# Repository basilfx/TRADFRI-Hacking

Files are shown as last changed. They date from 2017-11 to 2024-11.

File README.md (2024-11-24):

# Hacking IKEA TRÅDFRI

  * [Introduction](#introduction)
  * [TRÅDFRI modules](#trådfri-modules)
  * [Product teardowns](#product-teardowns)
  * [Firmware hacking](#firmware-hacking)
  * [Other hacks](#other-hacks)
    * [EZSP Zigbee coordinator](#ezsp-zigbee-coordinator)
    * [Zigbee router](#zigbee-router)
    * [FLOALT brightness hack](#floalt-brightness-hack)
    * [Shortcut button "no double press" hack](#shortcut-button-no-double-press-hack)
    * [DOOM](#doom)
  * [Sources](#sources)
  * [License](#license)
  * [Safety](#safety)
  * [Disclaimer](#disclaimer)

## Introduction
The [IKEA TRÅDFRI](http://www.ikea.com/us/en/catalog/categories/departments/lighting/36812/)
family of products provide you with several home automation solutions that
interconnect using [Zigbee Light Link](http://www.zigbee.org/zigbee-for-developers/applicationstandards/zigbee-light-link/).
While the line-up initially only included lighting products, it includes power
switches and wireless window blinds as well.

Many of the TRÅDFRI are quite simple. For instance, if we take a simple light
bulb, it contains:

* Power supply
* LED driver
* IKEA TRÅDFRI module

The IKEA TRÅDFRI module is used in many of their products, and is actually
a small piece of circuit board with a few GPIO pins exposed. These pins are
then used to control the LED driver.

The goal of this project is to provide information about the IKEA TRÅDFRI
modules and products, so you can start hacking them. For example:

* Take apart a light bulb, and use the module board, to control your own
  lighting solutions.
* Create custom boards for wall-mounted switches based on their dimmer buttons.
* Patch the firmware to dimming capabilies.
* Repurposing the modules by writing your own firmware.

To find relevant products, I have compiled a list of IKEA TRÅDFRI products in
[PRODUCTS.md](PRODUCTS.md). A teardown of has also been provided for some
products.

## TRÅDFRI modules
So far, a few variations of the TRÅDFRI modules have been identified. They are
all using microcontrollers manufactured by Silicon Labs. The modules that have
been identified are:

* ICC-1
* ICC-A-1
* MGM210L

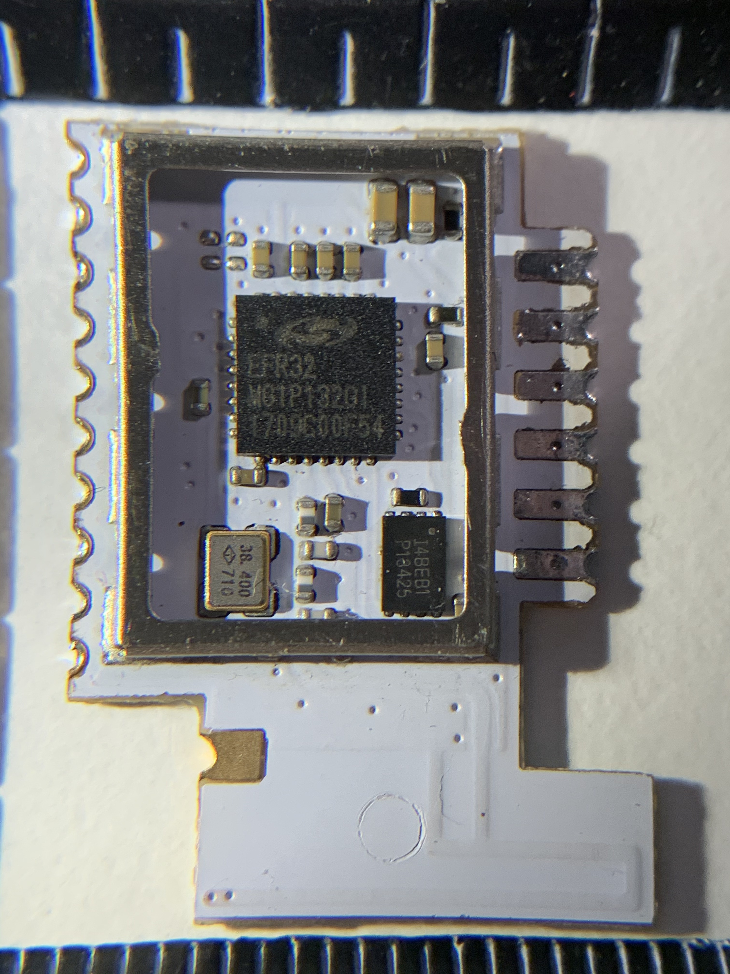
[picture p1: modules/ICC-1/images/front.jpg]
Front of IKEA TRÅDFRI module (ICC-1)
[](modules/ICC-1/images/front.jpg)
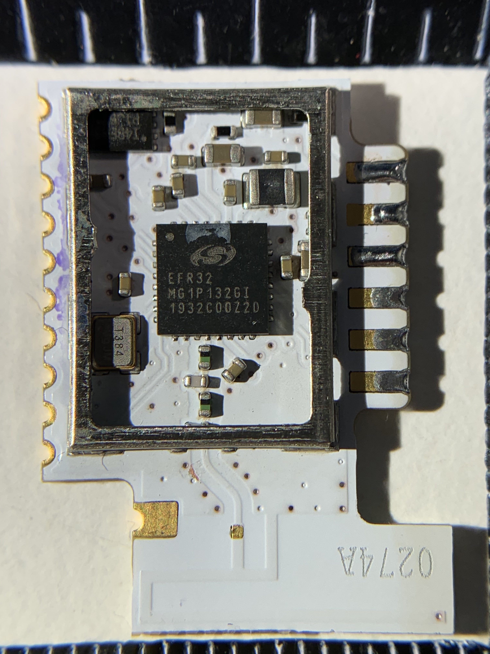
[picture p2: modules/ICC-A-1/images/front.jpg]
Front of IKEA TRÅDFRI module (ICC-A-1)
[](modules/ICC-A-1/images/front.jpg)
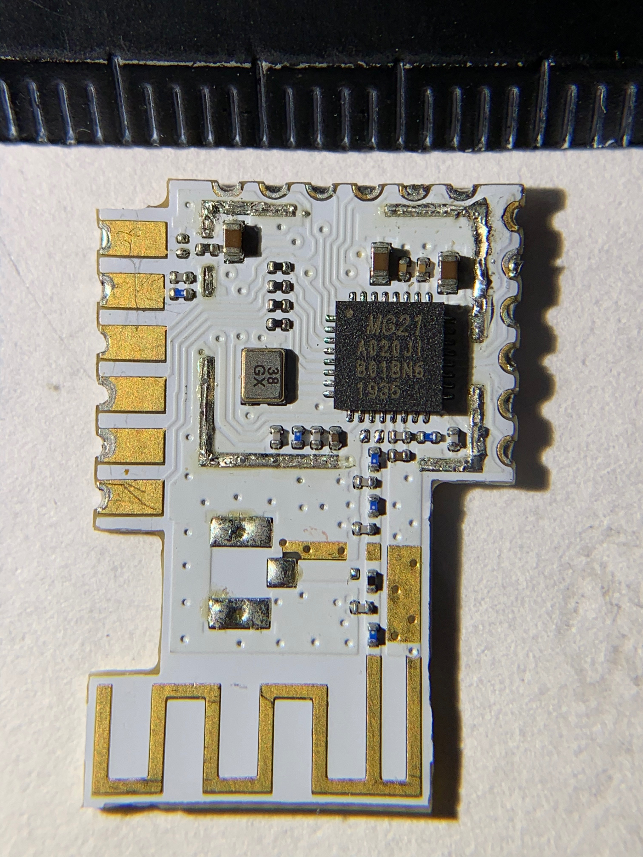
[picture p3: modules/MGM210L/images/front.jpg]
Front of IKEA TRÅDFRI module (MGM210L)
[](modules/MGM210L/images/front.jpg)

Some other products, such as the line-up of remote controls, have a dedicated
circuit board that integrate a microcontroller directly (i.e. no separate
module board).

More details and pictures on these modules can be found in
[MODULES.md](MODULES.md).

## Product teardowns
Be sure to check out the [PRODUCTS.md](PRODUCTS.md) on more details on products
that have been reversed-engineered. There are product teardown photos,
schematics, firmware dumps, firmware analysis and more.

If you have any products not in the list, please contribute! If you have any
teardown photos, firmware files or other information, I'd like to add it to the
list.

## Firmware hacking
The TRÅDFRI products use an ARM Cortex M-series microcontroller. There are
plenty of tools for these types of microcontrollers to get started on reversing
firmware files and write your own firmwares.

* Find dumps of firmware files in the OTA [folder](contrib/firmwares/ikea-ota).
* Checkout the [RIOT-OS](contrib/firmwares/riot-os) folder for more information
  on custom firmware development. You can use this as a starting point.
* Reference information on dumping firmware images [here](docs/firmware_dumping/README.md).
* Learn how to inspect the firmware for reverse-enginering in [this](docs/firmware_reversing)
  folder.
* Build a [development board](contrib/pcbs/devboard) for easy access to a
  TRÅDFRI module's pins.

## Other hacks
Some people have came up with alternative uses for the TRÅDFRI modules. Here
are a few:

### EZSP Zigbee coordinator
It is possible to load the Silicon Labs EmberZNet Zigbee coordinator firmware
on an ICC-1 or ICC-A-1. This allows you to use the module to set-up your own
Zigbee network.

MattWestb has provided a guide and firmware [here](https://github.com/MattWestb/IKEA-TRADFRI-ICC-A-1-Module).

### Zigbee router
Several users have [modified](https://community.home-assistant.io/t/sonoff-zbbridge-sonoff-zigbee-bridge-from-itead/187346/88)
the TRÅDFRI routers to improve the performance, by adding an external antenna.

This applies to the ICC-A-1 modules only, but it should be very interesting
if a the TRÅDFRI routers will use the newer MGM210L modules, because they offer
a solder pad for an external antenna.

### FLOALT brightness hack
[zw](https://github.com/zw) has patched the firmware of his FLOALT LED panel to
have an improved range of brightness levels. A guide to perform the firmware
patch has been contributed [here](https://github.com/zw/TRADFRI-Hacking/tree/master/hacks/L1527).

### Shortcut button "no double press" hack
Simon has [patched](https://github.com/nomis/ikea-tradfri-e1812) the firmware
of the E1812 shortcut button to disable the double press feature, getting rid
of the 400ms delay on single presses.

### DOOM
A version of DOOM was port to the IKEA TRÅDFRI MGM210L modules, including a
custom contrller. The project is documented [here](https://next-hack.com/index.php/2021/06/12/lets-port-doom-to-an-ikea-tradfri-lamp/)
and the source code can be found [here](https://github.com/next-hack/MG21DOOM).

## Sources
I have gathered some information from the following sources:

* [IKEA TRÅDFRI hacking](https://tradfri.blogspot.nl)
* [TRÅDFRI: ESP8266-Lampen-Gateway](https://www.heise.de/make/artikel/Ikea-Tradfri-Anleitung-fuer-ein-ESP8266-Lampen-Gateway-3598411.html)
* [TRÅDFRI Zigbee Light Link module](https://diystuff.nl/tradfri/tradfri-zigbee-light-link-module)
* [TRÅDFRI Wall switch](https://wiki.permejdal.dk/TR%C3%85DFRI_wall_switch)

## License
See the [LICENSE.md](LICENSE.md) file (CC-BY-4.0).

## Safety
Some TRÅDFRI products are mains powered. If you don't know what that means, then
stop right now. Please read [this](docs/working_safely) for more information on
working safely on mains-connected devices.

## Disclaimer
This page and its content is not affiliated with IKEA of Sweden AB.

The purpose of this project is to learn and improve using reverse engineering
techniques. Use this information on your own risk. You will void your warranty.

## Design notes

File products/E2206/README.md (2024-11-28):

# E2206
INSPELNING smart switch with energy monitoring.

This is very similar to the [E2204](../E2204), but has a few additional parts
populated for energy monitoring.

## Details

* Potted: tiny bit
* Module: unidentified

## Teardown
Remove the screw in the middle (security screw). Then use a pry tool to remove
the front casing, paying attention to the raised border and the tabs on all
four sides

Once inside, remove the two small screw from the main board. One corner is
slightly potted, but it is quite brittle and does not really adhere to the
casing. You can heat up the corner using a heat gun to make it softer.

Then firmly push on the contact pins to remove the board from its housing.
Place the pins on a hard surface, then push the case down. Be aware that the
switch domes must be bent inwards, otherwise they will be damaged.

* [Images](images)

## Parts

* U3: [Hiliwei Tech HLW8110](https://redmine.laas.fr/attachments/download/3444/DS_HLW8110_HLW8112_EN_Rev1.01%20.pdf)

## Sources

* https://www.ikea.com/us/en/manuals/tretakt-plug-smart__AA-2396101-2-100.pdf

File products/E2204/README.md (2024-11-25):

# E2204
TRETAKT smart switch

## Details

* Potted: no
* Module: unidentified

## Teardown
Remove the screw in the middle (security screw). Then use a pry tool to remove
the front casing, paying attention to the tabs on all four sides.

Once inside, remove the two small screw from the main board. Then gently push
on the contact pins to remove the board from its housing. Be careful, because
you can easily damage the switches.

* [Images](images)

## Sources
* https://www.ikea.com/us/en/manuals/tretakt-plug-smart__AA-2396101-2-100.pdf

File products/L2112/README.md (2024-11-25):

# L2112
ORMANÄS LED strip, color/white spectrum, 4 m.

## Details

* Potted: no
* Module: MGM210L

## Teardown
The device can be easily opened. There are six tabs that keep the lid in place
(see pictures). Using a plastic pry tool, you should be able to open the device
without any damage.

* [Images](images)

## Sources

* https://www.ikea.com/us/en/assembly_instructions/ormanas-led-strip-smart-draadloos-dimbaar-gekleurd-en-wit-spectrum__AA-2364567-3-2.pdf

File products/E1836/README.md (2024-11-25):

# E1836
ÅSKVÄDER on/off button.

## Details

* Potted: no
* Module: MGM210L

## Teardown
This product is securely enclosed, and can only be opened destructively. I
found it the easiest to use a hacksaw (or a Dremel) to cut the sides, so it can
be opened up.

* [Images](images)

## Sources
* https://www.ikea.com/us/en/assembly_instructions/askvader-aan-uitknop__AA-2248628-2-2.pdf

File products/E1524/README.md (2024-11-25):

# E1524
TRÅDFRI remote controller.

## Pinout

### Module

* PB15 -> Color temperature
* PB14 -> Dim -
* PC10 -> On/Off
* PB13 -> TX
* PA1 -> Dim +
* PA0 -> TouchLink button

## Sources

* https://www.ikea.com/us/en/manuals/tradfri-remote-control__AA-2144721-1_pub.pdf
* https://www.heise.de/make/artikel/Ikea-Tradfri-Anleitung-fuer-ein-ESP8266-Lampen-Gateway-3598411.html

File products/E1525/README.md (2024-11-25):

# E1525
TRÅDFRI motion sensor.

## Details:

* Battery: 2x CR2032

## Teardown
The module is easy to take apart, and debug wires can be soldered on without
separating the radio / MCU PCB from the carrier PCB. The carrier board is
labelled "D-Sensor-A1-01-A-V2.0".

* [Images](images)
* [Schematics](schematics)

## Pinout

### Module

| Module Pin | Signal |
|---|---|
| PA0 | Switch Input |
| PA1 | Timer Input (Voltage Divider) |
| PB12 | Nothing? Has a capacitor position |
| PB13 | Photoresistor Analog |
| PB14 | PIR Interrupt |
| PB15 | Day/Night Analog |
| PC10 | PIR Serial Connection |

### PCB

| Test Point | Signal |
|---|---|
| TP1_X | Day/Night Potentiometer Analog |
| TP2_X | Photoresistor Analog Output |
| TP3_X | Ground |
| TP4_X | Switch Output |
| TP5_X | Timer Potentiometer Analog |
| TP7_X | LED |
| TP8_X | Power Supply |

* Time selection dial (R13): PA1 (Looks like a potentiometer between R12 high
  side and a FET to GND enabled directly by PB14.)
* Day/night selection dial (R15): PB15 (Dito, with resistor R14 and same
  transistor.)
* Pairing button (S1): Silicone rubber button puling PA0 directly to GND

The motion detection dome is connected (one pin directly, one indirectly) to
an "E93196C 5090C 9A" labelled 8-pin chip to which also PC10 and PB14 are
connected (needs further investigation).

## Sources

* https://www.ikea.com/us/en/manuals/tradfri-wireless-motion-sensor-white__AA-2145281-3.pdf

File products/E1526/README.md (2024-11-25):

# E1526
TRÅDFRI hub.

## Details

* Power supply: USB 5V 1A

## Protocol
An overview of the COAP protocol used by the gateway can be found
[here](https://github.com/glenndehaan/ikea-tradfri-coap-docs).

## Sources
* https://www.ikea.com/us/en/manuals/tradfri-poarta__AA-1954427-3_pub.pdf

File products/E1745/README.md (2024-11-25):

# E1745
TRÅDFRI motion sensor.

## Details

* Battery: 2x CR2032

## Teardown
Module is easy to take apart with the right tools, debug wires could be
soldered on without separating the radio from the carrier PCB. The carrier
board is labelled "D-SS-X2-01-A-V2.1" and the date printed is 2018-06-05.
Tradfri module markings visible are Draco1.0_105° and 0255C.

* [Images](images)

## Pinouts

### Module
TRÅDFRI Module (unverified):

* tK1 -> Day/Night selection button
* tK2 -> Pairing button
* tK3 -> Time selection button

The motion detection dome is connected (one pin directly, one indirectly) to
an "E93196B 0940A 60A" labelled 8-pin chip. This appears to be
[Elmos E931.96](https://www.elmos.com/english/products/sensor-ics/passive-infrared/pyroelectric-sensor-signal-processor-ssp/e93196.html).

### PCB
Various test points:

* VCC: `VDD`
* GND: `GND`
* Pairing BTN: `tK2`
* Day/Night BTN: `tK1`
* Time Select BTN: `tK3`
* ???: `AL`
* ???: `ENT`
* ???: `TX1`

## Sources
* https://www.ikea.com/us/en/manuals/tradfri-motion-sensor-kit__AA-1954408-1_pub.pdf

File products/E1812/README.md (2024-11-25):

# E1812
TRÅDFRI shortcut button.

## Teardown
* [Images](images)

## Sources
* https://www.ikea.com/us/en/manuals/tradfri-remote-control-white-smart__AA-2198134-5-100.pdf

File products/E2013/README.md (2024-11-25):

# E2013
PARASOLL door/window sensor.

## Details

### Battery
This sensor runs off a 1.2 or 1.5 AAA battery, which increases the size of the
sensor.

When connecting it to a 3V power supply, it does work. It might be possible
that the DC-DC converter can be omitted in this case. However, the hall-effect
sensor emits a higher voltage level that represents a closed state.

## Teardown
* [Images](images)

## Parts
* R1 - 1 M
* R2 - 1 M
* R3 - 100 k
* R7 - 200
* R12 - 0

* U1 - EFR32MG24B020F1536IM40 (microcontroller)
* U2 - ? (hall-effect sensor)
* U3 - OC6811 (DC-DC converter)

* Y1 - 39 Mhz

## Sources
* https://www.ikea.com/us/en/manuals/parasoll-sensor-puerta-ventana-inteligente-blanco__AA-2426062-2-2.pdf
* https://fcc.report/FCC-ID/FHO-E2013/

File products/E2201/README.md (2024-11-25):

# E2201
RODRET wireless dimmer.

## Teardown
* [Images](images)

## Sources
* https://www.ikea.com/us/en/manuals/rodret-wireless-dimmer-power-switch-smart-white__AA-2398767-2-100.pdf

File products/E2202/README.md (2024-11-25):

# E2202
BADRING water leakage sensor.

## Details
Powered by a single AAA cell, boosted to 3.0V by the onboard DC-DC converter.
The inner plastic retainer is held with plastic clips, which makes the device
very easy to disassemble.

Teardown images can be found with FCC ID FHO-E2202.

## Parts

- U1: EFR32MG21A010F1024IM32
- Q1: 2N3904
- Q2: 2N3904
- Q3: Si2301

## Pinout

- PA00 PIN2 (input, driven by Q2)
- PA01 CLK (test pad)
- PA02 TMS (test pad)
- PA03 S1 (button, with pull-up)
- PA05 LED+
- PA06 VBAT
- PB00 Buzzer (driven by Q1)
- PD01 TX (test pad)
- PD00 RX (test pad)
- PD04 PIN1 (output, driven by Q3)

## Notes

The device is sending out some pulses on PIN1 and listening for a signal on
PIN2. Frequency is unknown, voltage is the same as VCC (3.0V). The chip is
locked, mass erase is required to load your own code to it.

## Sources

* https://www.ikea.com/us/en/manuals/badring-sensor-foer-vattenlaeckage-smart__AA-2426054-2-2.pdf

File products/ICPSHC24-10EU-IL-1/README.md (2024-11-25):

# ICPSHC24-10EU-IL-1
Driver for wireless control, 10 W

## Teardown

* [Images](images)

## Sources

* https://www.ikea.com/us/en/assembly_instructions/tradfri-driver-for-wireless-control-smart-grey__AA-2056440-8-100.pdf

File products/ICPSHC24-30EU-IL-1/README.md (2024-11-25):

# ICPSHC24-30EU-IL-1
Driver for wireless control, 30 W

## Teardown

* [Images](images)

## Sources

* https://www.ikea.com/us/en/manuals/tradfri-driver-for-wireless-control-grey__AA-2344761-1-100.pdf

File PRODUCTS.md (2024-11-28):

# List of IKEA TRÅDFRI products

* [Introduction](#introduction)
* [Product overview](#product-overview)
* [Catalog](#catalog)
  * [Lighting](#lighting)
  * [Remotes](#remotes)
  * [Sensors](#sensors)
  * [Gateways](#gateways)
  * [Others](#others)

## Introduction
This list is a collection of the IKEA TRÅDFRI products, and their relevant
technical properties. Please help me to update this list.

## Product overview
IKEA has following products and product categories for the Smart Home series
(also called TRADFRI):

* Smart Home Gateway
* FLOALT (light panel)
* GUNNARP (ceiling/wall lamp)
* LEPTITER (spotlight)
* IRSTA  (worktop lighting)
* OMLOPP (spotlight)
* STRÖMLINJE (worktop lighting)
* SKYDRAG (worktop lighting)
* FYRTUR / KADRYL (window blinds)
* 5-button remote control (V1 and V2)
* 2-button dimmer/switch
* Wheel dimmer
* Shortcut button
* Motion detector (V1 and V2)
* Signal repeater + battery charger
* Switching outlet plug/mains
* LED driver 10 W with 3 connections
* LED Driver 30 W
* Bulb E27 1000 lm white/warmwhite
* Bulb E27 800 lm warmwhite
* Bulb E27 800 lm white/warmwhite transparent
* Bulb E27 600 lm color
* Bulb E14 600 lm color
* Bulb E14 600 lm white/warmwhite
* Bulb E27 250 lm filament gold
* Bulb GU10 400 lm warmwhite
* Bulb GU10 400 lm white/warmwhite
* Bulb GU10 350 lm color

## Catalog

### Lighting

* [L1529](products/L1529) - FLOALT LED light panel
* [L2112](products/L2112) - ORMANÄS LED strip, color/white spectrum, 4 m
* [LED1536G5](products/LED1536G5) - TRÅDFRI bulb E12/E14, white spectrum, globe, opal, 400 lm
* [LED1537R6](products/LED1537R6) - TRÅDFRI bulb GU10, white spectrum, 400 lm
* [LED1545G12](products/LED1545G12) - TRÅDFRI bulb E26/E27, white spectrum, globe, opal, 980 lm
* [LED1546G12](products/LED1546G12) - TRÅDFRI bulb E26/E27, white spectrum, globe, clear, 950 lm
* [LED1622G12](products/LED1622G12) - TRÅDFRI bulb E26, white, globe, opal, 1000 lm.
* [LED1623G12](products/LED1623G12) - TRÅDFRI bulb E27, white, globe, opal, 1000 lm
* [LED1624G9](products/LED1624G9) - TRÅDFRI bulb E12/E14/E26/E27, color/white spectrum, globe, opal, 600 lm
* [LED1650R5](products/LED1650R5) - TRÅDFRI bulb GU10, white, 400 lm
* [LED1837R5](products/LED1837R5) - TRÅDFRI bulb GU10, warm white, 400 lm
* [LED1923R5](products/LED1923R5) - TRÅDFRI bulb GU10, color/white spectrum, 345 lm

### Remotes

* [E1524](products/E1524) - TRÅDFRI Remote controller
* [E1812](products/E1812) - TRÅDFRI Shortcut button
* [E2123](products/E2123) - SYMFONISK remote controller
* [E2201](products/E2201) - RODRET wireless dimmer
* [ICTC-G-1](products/ICTC-G-1) - TRÅDFRI wireless dimmer

### Sensors

* [E1525](products/E1525) - TRÅDFRI motion sensor
* [E1745](products/E1745) - TRÅDFRI motion sensor
* [E2013](products/E2013) - PARASOLL door/window sensor
* [E2202](products/E2202) - BADRING water leakage sensor

### Gateways

* [E1526](products/E1526) - TRÅDFRI hub

### Others

* [E1836](products/E1836) - ÅSKVÄDER on/off button
* [E2204](products/E2204) - TRETAKT smart switch
* [E2204](products/E2206) - INSPELNING smart switch with energy monitoring
* [ICPSHC24-10EU-IL-1](products/ICPSHC24-10EU-IL-1) - Driver for wireless control, 10 W
* [ICPSHC24-30EU-IL-1](products/ICPSHC24-30EU-IL-1) - Driver for wireless control, 30 W
* [ICPSLC24-10NA](products/ICPSLC24-10NA) - LED output controller/dimmer

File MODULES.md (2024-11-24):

# Modules

* [Types of modules](#types-of-modules)
* [ICC-1 and ICC-A-1](#icc-1-and-icc-a-1)
  * [Components](#components)
  * [Pinout](#pinout)
  * [JTAG](#jtag)
  * [Pictures](#pictures)
* [MGM210L](#mgm210l)
  * [Components](#components-1)
  * [Pinout](#pinout-1)
  * [Flashing using JTAG](#flashing-using-jtag)
  * [Pictures](#pictures-1)

## Types of modules
Many TRÅDFRI products make use of a common board that houses the
microcontroller that is responsible for running the firmware and Zigbee.
This makes it for IKEA much easier to reuse hardware, especially from a
certification perspective.

However, several other TRÅDFRI products have the microcontroller integrated on
the 'core' product board, which makes it possible to design smaller products,
or products with a different form factor. However, they are less usable when
you want to repurpose them. Therefore, they are not part of the sections below.

## ICC-1 and ICC-A-1
The ICC-1 is the first module used by many of the first TRÅDFRI products.

In January 2020 I bought the successor of the cheapest TRÅDFRI LED bulb (the
LED1837R5) and it contains an updated module (ICC-A-1). It looks like some
components have been moved, but all the part numbers look the same. I have
included updated pictures in the [Pictures](#pictures) section.

The only difference I have found (so far), is that PF3 is no longer an output
pin, but used to enable the SPI NOR Flash.

### Components
Both modules use the same energy-efficient microcontroller manufactured by
Silicon Labs. It is an EFR32 Mighty Gecko (Series 1), based around an
ARM Cortex M4 with 256 KiB of flash and 32 KiB of memory. This makes it a very
capable microcontroller.

I have been able to identify the following parts:

* Microcontroller: [EFR32MG1P132F256GM32](https://www.silabs.com/wireless/zigbee/efr32mg1-series-1-socs/device.efr32mg1p132f256gm32)
* 2 Mbit SPI NOR Flash: [IS25LQ020B](http://www.issi.com/WW/pdf/25LQ025B-512B-010B-020B-040B.pdf)
* Crystal: 38.4 MHz

I am very certain that the SPI NOR Flash component is correct. The original
firmware contains strings that refer to the exact part number. However, it also
contains references to other SPI flash components, so your module may contain
another one. The JEDEC ID it responds with is `9d 40 12`.

### Pinout
The pinout of both modules is very similar.

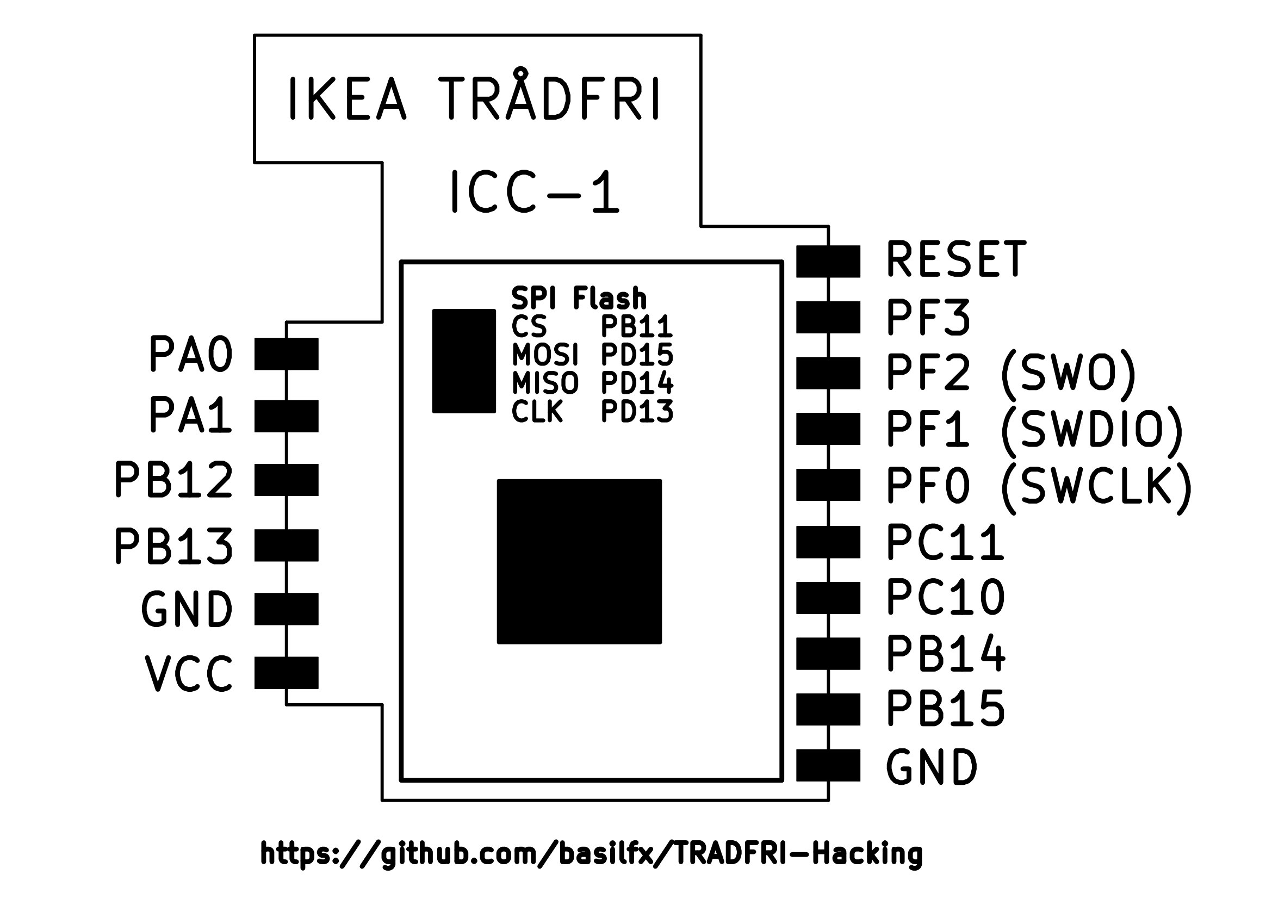
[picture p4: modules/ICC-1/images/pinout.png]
Back of IKEA TRÅDFRI module (ICC-1)
[](modules/ICC-1/images/pinout.png)
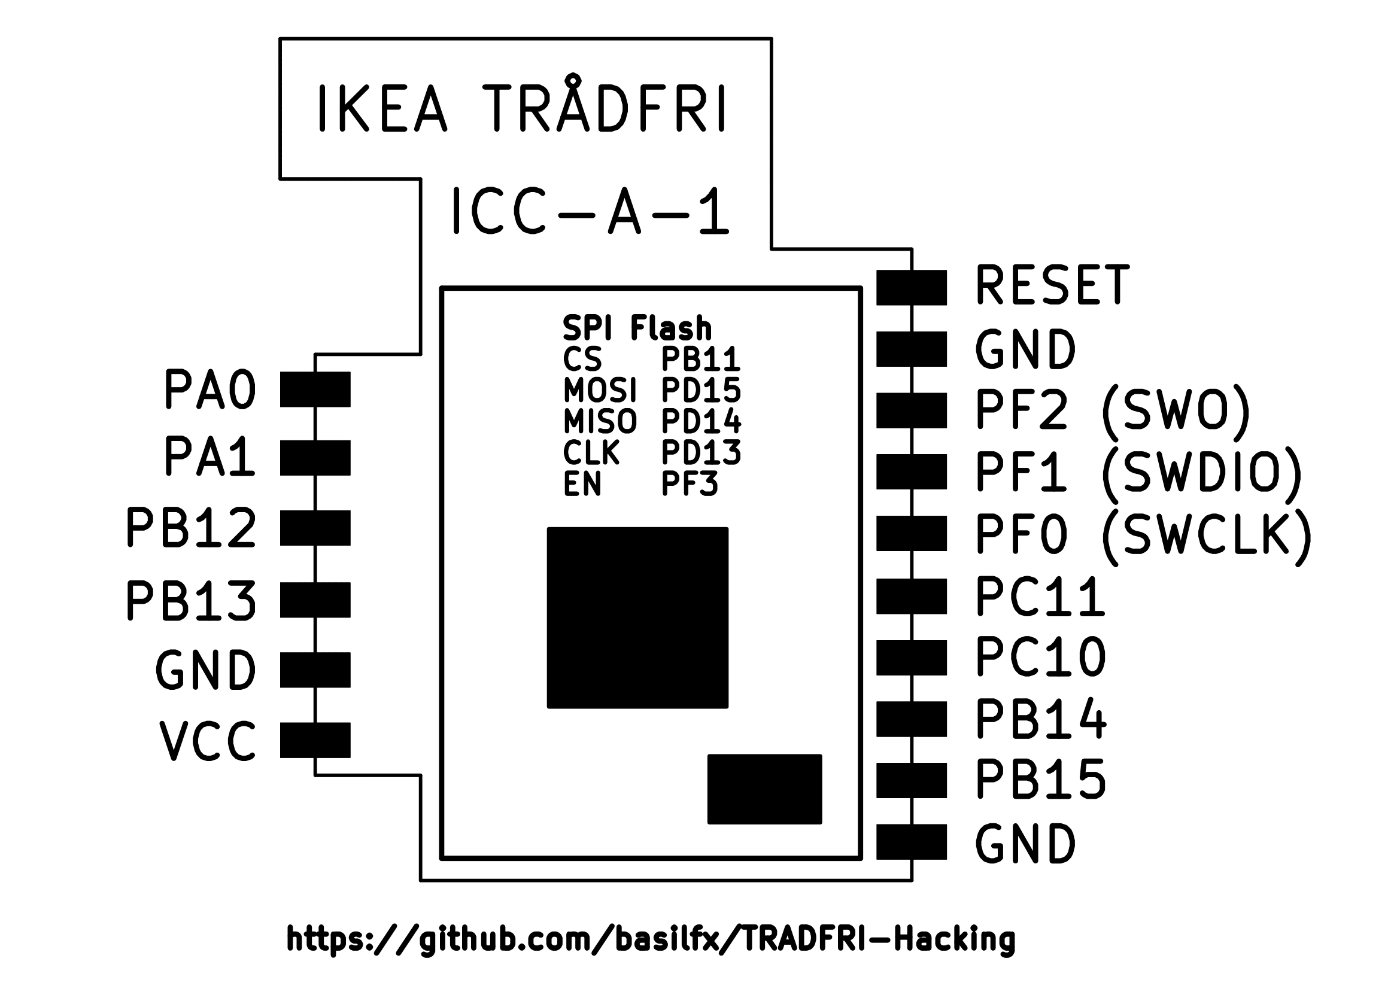
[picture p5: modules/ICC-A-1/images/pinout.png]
Back of IKEA TRÅDFRI module (ICC-A-1)
[](modules/ICC-A-1/images/pinout.png)

[Marco van Nieuwenhoven](https://diystuff.nl/tradfri/tradfri-zigbee-light-link-module/)
has provided a very detailed teardown of the ICC-1 module. He traced most of
the copper traces and created a schematics on his website.

### JTAG
To connect to an external JTAG/SWD debugger, connect as follows:

* PF0 -> SWCLK
* PF1 -> SWDIO
* PF2 -> SWO
* RESETn -> RESETn
* GND -> GND
* VCC -> VCC (3V3)

The first ICC-1 modules I salvaged, was part of a light bulb. I could leave it
in-place for flashing, as long as I provided my own power supply by hooking it
up to the VCC line directly (NEVER flash a module that is connected to live
power).

[OpenOCD](https://github.com/sysprogs/openocd/blob/master/tcl/target/efm32.cfg)
and [J-Link](https://wiki.segger.com/EFM32) are two popular debuggers that can
be used for flashing and debugging.

### Pictures
I have extracted modules from the LED1650R5 (ICC-1) and the LED1837R5 (ICC-A-1).

Front of two TRÅDFRI modules:

[Front of IKEA TRÅDFRI module (ICC-1)](modules/ICC-1/images/front.jpg)
[Front of IKEA TRÅDFRI module (ICC-A-1)](images/icc-a-front.jpg)

Back of two TRÅDFRI modules:

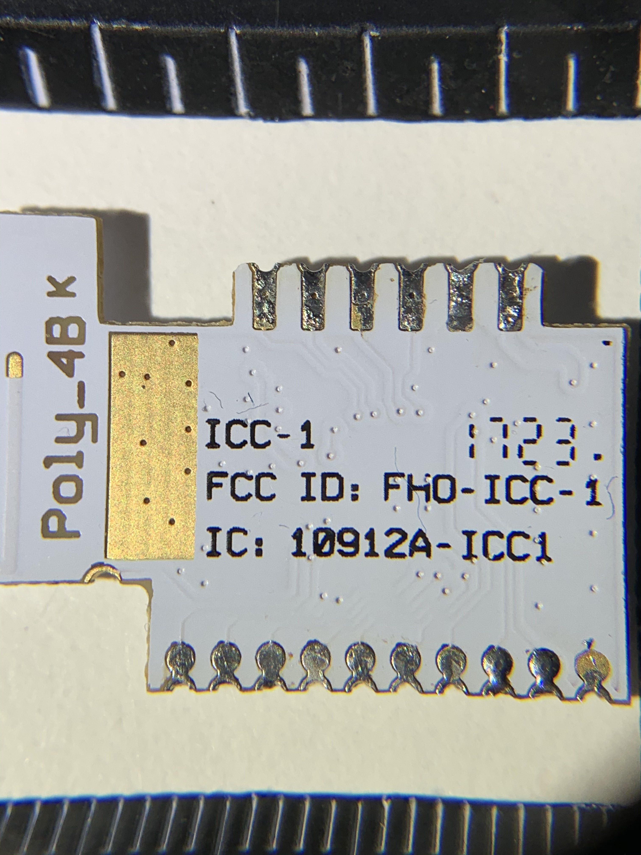
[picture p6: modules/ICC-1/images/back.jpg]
Back of IKEA TRÅDFRI module (ICC-1)
[](modules/ICC-1/images/back.jpg)
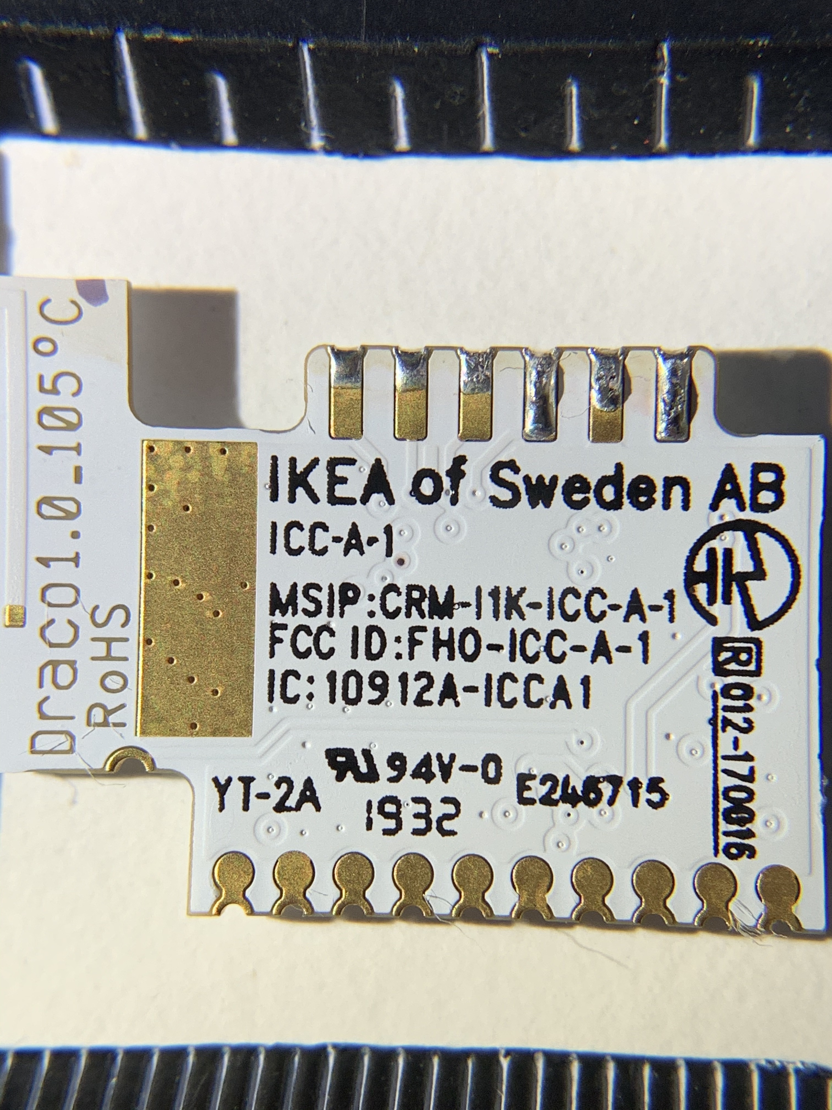
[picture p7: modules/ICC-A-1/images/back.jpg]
Back of IKEA TRÅDFRI module (ICC-A-1)
[](modules/ICC-A-1/images/back.jpg)

## MGM210L
Another module variant was identified by @CableCatDK in [issue 39](https://github.com/basilfx/TRADFRI-Hacking/issues/39).
This module seems to be an off-the-shelve module not specifically designed for
IKEA TRÅDFRI.

### Components
An energy-efficient microcontroller manufactured by Silicon Labs is used on
this board. It is an EFR32 Mighty Gecko (Series 2), based around an
ARM Cortex M33 with 1024 KiB of flash and 96 KiB of memory.

* Microcontroller: [EFR32MG21A010F1024IM32](https://www.silabs.com/wireless/zigbee/efr32mg21-series-2-socs/device.efr32mg21a010f1024im32)
* Crystal: 38.4 MHz

Contrary to the previous generation of modules, this board does not have a
SPI NOR flash chip.

The PCB has room for an U.FL external antenna connector.

### Pinout
A pinout can be in the [user manual](https://www.silabs.com/documents/public/data-sheets/mgm210l-datasheet.pdf).

### Flashing using JTAG
To connect to an external JTAG/SWD debugger, connect as follows:

* PA1 -> SWCLK
* PA2 -> SWDIO
* PA3 -> SWO
* RESETn -> RESETn
* GND -> GND
* VCC -> VCC (3V3)

Support for the EFR32MG21 (and Series 2 in general) is limited. There exists a
separate [fork](https://github.com/knieriem/openocd-efm32-series2) for OpenOCD.
J-Link offers support, but requires more-expensive hardware to get started.

### Pictures
Front the TRÅDFRI module:

[Back of IKEA TRÅDFRI module (ICC-1)](modules/MGM210L/images/front.jpg)

Back of the TRÅDFRI module:

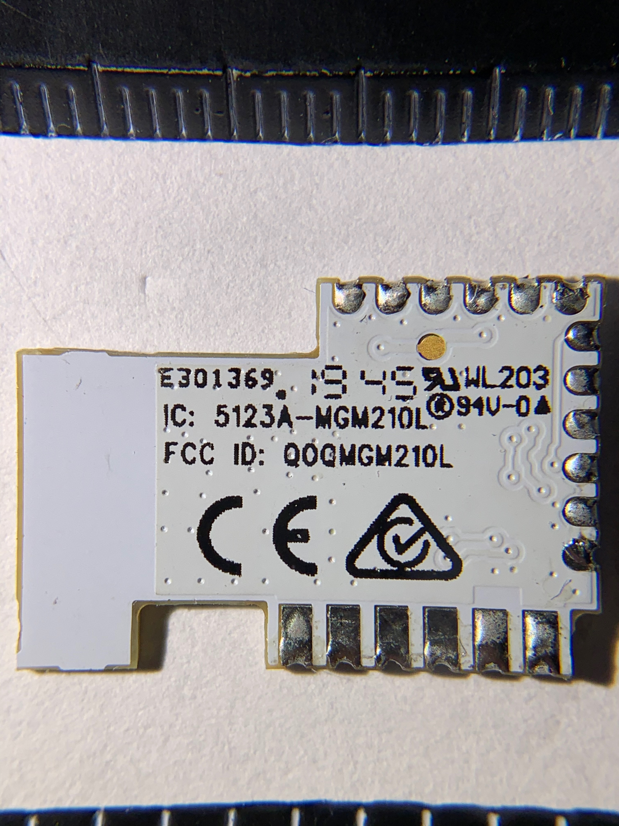
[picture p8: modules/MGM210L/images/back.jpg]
Back of IKEA TRÅDFRI module (ICC-1)
[](modules/MGM210L/images/back.jpg)

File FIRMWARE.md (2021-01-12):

# Analysis of firmware

* [Introduction](#introduction)
* [Dumping firmware](#dumping-firmware)
  * [J-Link](#j-link)
* [Flash layout](#flash-layout)
* [SPI NOR flash contents](#spi-nor-flash-contents)
* [References](#references)
  * [Source files](#source-files)

## Introduction
This document describes my findings of the IKEA TRÅDFRI firmware downloaded
from the GU10 light bulb (LED1650R5). According to the binary, it contained
version 1.2.214. As of writing, this was the latest firmware available.

## Dumping firmware
To dump (or flash) firmware of a module, you have to use an external debugger.
I have used a [STK3600](https://www.silabs.com/development-tools/mcu/32-bit/efm32lg-starter-kit)
in debugger output mode.

You can use software like [JLink](https://www.segger.com/products/debug-probes/j-link/)
or [OpenOCD](http://www.openocd.org) to flash the target.

### J-Link
If you use J-Link, you can use the command below to connect to the ICC-1 or
ICC-A-1 module:

```
JLink -If SWD -Speed 5000 -Device EFR32MG1PXXXF256
```

To dump the flash contents, use the command below (0x40000 is 256 KiB):

```
savebin output.bin 0x0 0x40000
```

To load a flash from file, use the following command:

```
loadbin output.bin 0x0
verifybin output.bin 0x0
```

I have confirmed that you can dump the flash, erase the device and load it
again, and the light bulb will still work.

## Flash layout
Inside the [strings](firmwares/ikea/led1650r5-1.2.214.strings), references are
made to certain C sources named `bootloader-interface-app.c`. This seems to
refer to Silicon Labs application note
[AN772](https://www.silabs.com/documents/public/application-notes/an772-using-legacy-application-bootloader.pdf).

This application note suggest a flash layout (figure 2.1) that looks like this:

* 0x00000 - 0x03fff -> Bootloader + recovery image (16 KiB)
* 0x04000 - 0x????? -> Application data
* 0x????? - 0x3ffff -> Simulated EEPROM

Looking at a binary map of the firmware (created using
[binvis.io](http://binvis.io)), we can clearly identify three regions, of which
the second region starts at 0x04000 and the third one at 0x3d000.

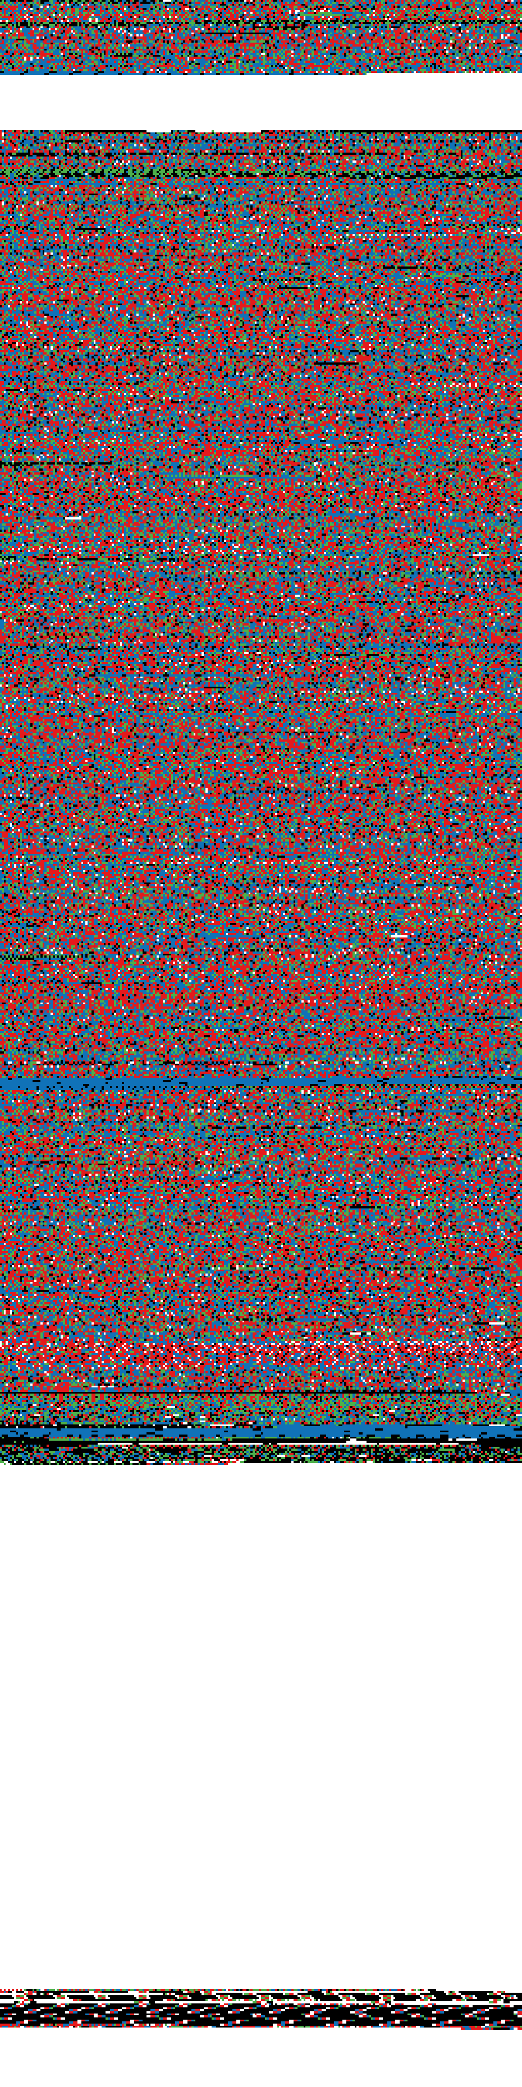
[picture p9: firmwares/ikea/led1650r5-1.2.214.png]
[](firmwares/ikea/led1650r5-1.2.214.png)

For completeness, not that there are also the [following](https://github.com/basilfx/TRADFRI-Hacking/issues/24#issuecomment-651145045)
memory addresses:

* 0x0fe00000 - 0x0fe00800 -> user data (2 KiB)
* 0x0fe10000 - 0x0fe12800 -> factory bootloader (10 KiB)

## SPI NOR flash contents
The board provides a 2 MBit (256KiB) SPI NOR Flash. Using the
[SPI Flash Dump](firmwares/riot-os/spi_flash_dump) utility, I dumped the flash
contents.

It seems seem that the flash chip is not used for this LED bulb. When dumping
its contents, it only reads 0xFF (I have verified this utility against a known
working flash chip before using).

## References

### Source files
There are several references to C source files. Below an overview of files
encountered.

* af-main-soc.c
* association.c
* bootloader-interface-app.c
* command.c
* counters-soc.c
* cstartup-iar.c
* eeprom.c
* ember-configuration.c
* ember-multi-network-stub.c
* ember-stack-common.c
* event-control.c
* mac-arbiter.c
* mac-efr32.c
* mac-info-element-parsing-stub.c
* mac-receive.c
* mac.c
* mfg-token.c
* micro-common.c
* micro-internal.c
* neighbor.c
* network.c
* ota-storage-eeprom-page-erase.c
* ota-storage-eeprom.c
* packet-buffer.c
* packet-header.c
* pGrf4ce-stack-stubs.c
* phy-common.c
* route-discovery.c
* route-table.c
* scan.c
* sim-eeprom2-internal.c
* sim-eeprom2-internal.c
* sleep-efm32.c
* system-timer.c
* token.c
* zigbee-stack.c

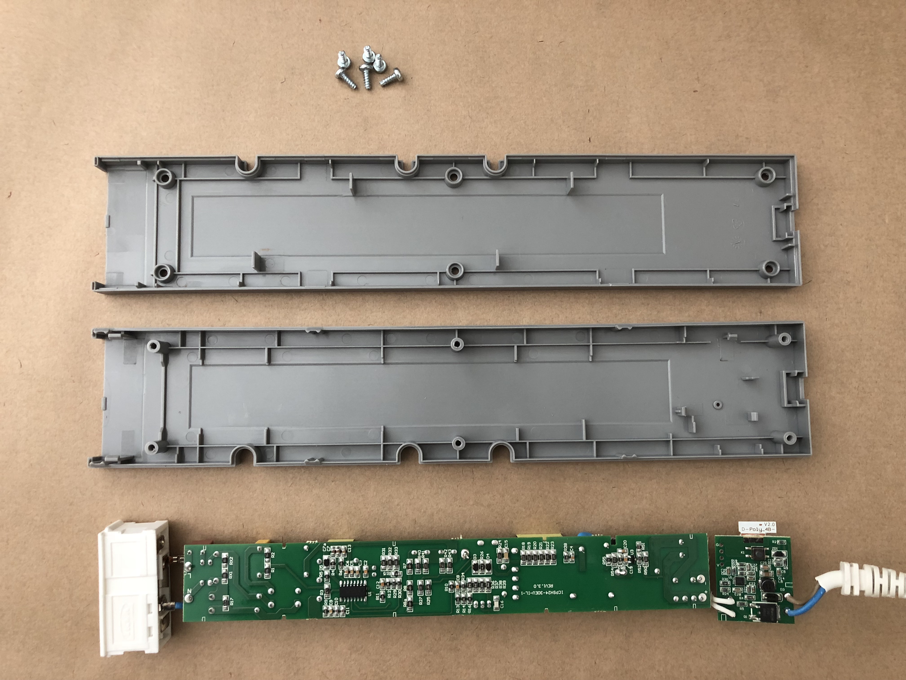
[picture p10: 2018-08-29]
products/ICPSHC24-30EU-IL-1/images/complete_electronics_01.jpg

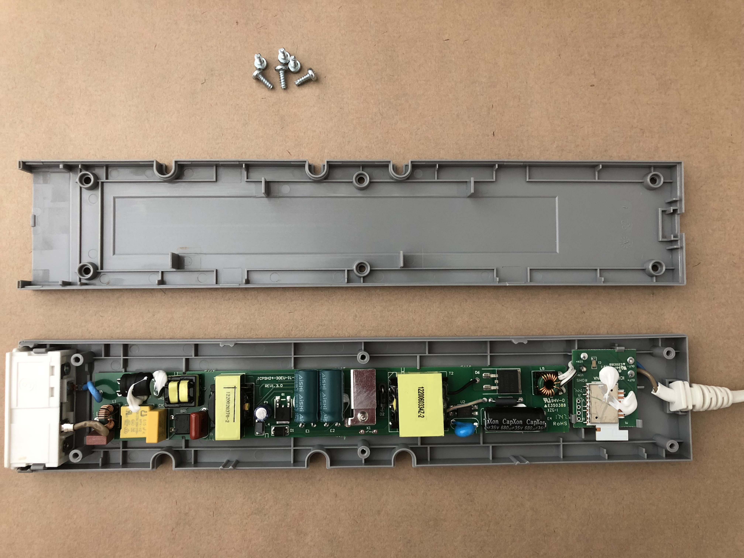
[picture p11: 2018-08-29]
products/ICPSHC24-30EU-IL-1/images/complete_electronics_02.jpg

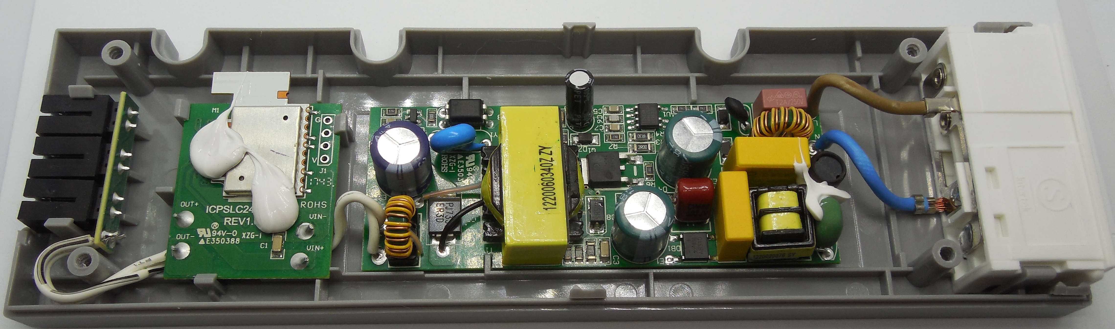
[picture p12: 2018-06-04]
products/ICPSHC24-10EU-IL-1/images/complete_electronics_01.jpg

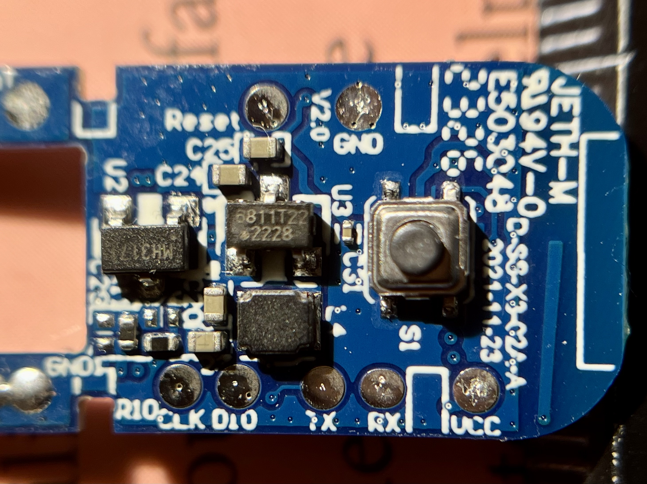
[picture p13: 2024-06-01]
products/E2013/images/pcb-front.jpg

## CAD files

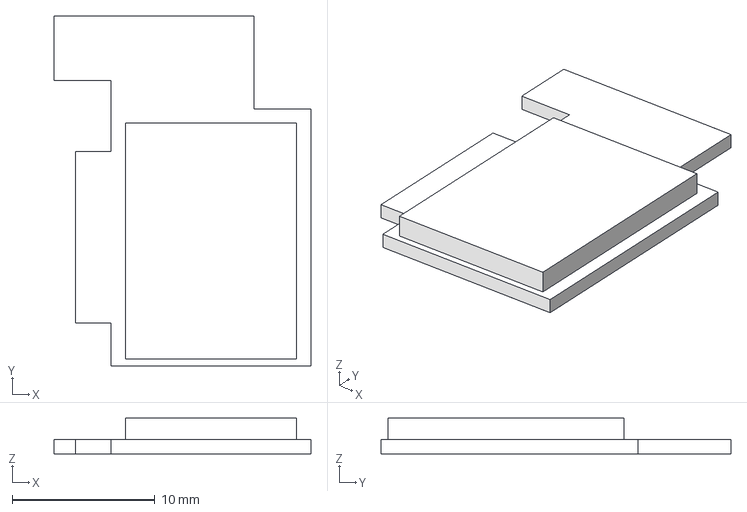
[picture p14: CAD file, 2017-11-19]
contrib/cad/tradfri.FCStd
18.0 x 24.5 x 2.50 mm

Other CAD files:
contrib/cad/tradfri.dxf
contrib/cad/tradfri.stl

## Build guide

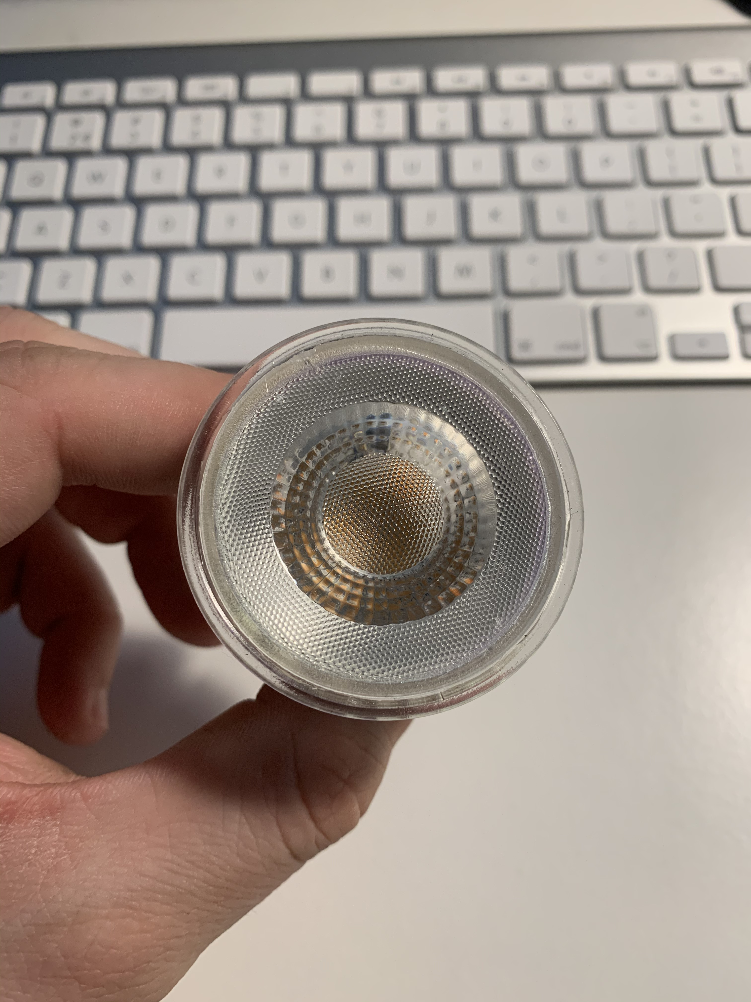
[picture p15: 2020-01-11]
products/LED1837R5/images/assembled.jpg

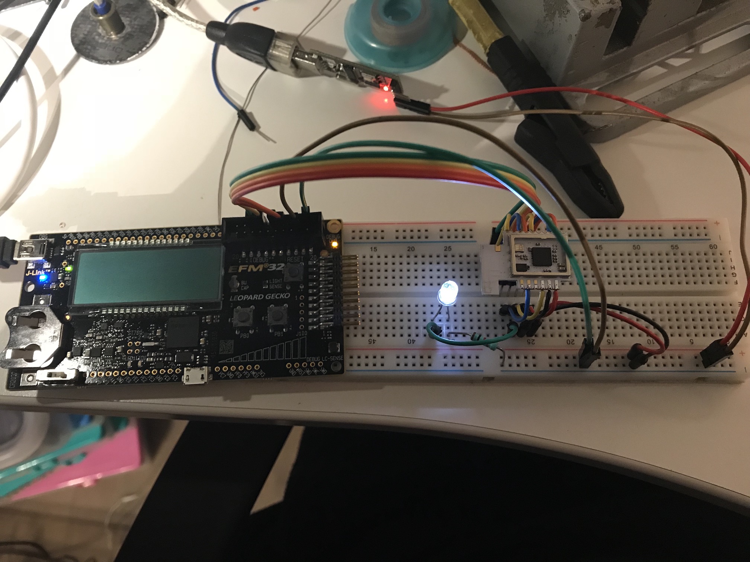
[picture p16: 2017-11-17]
docs/working_safely/images/setup2.jpg

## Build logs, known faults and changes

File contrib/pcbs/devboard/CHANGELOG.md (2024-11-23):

# Changelog

## v1.0.1
Released 23 November 2024

Highlights:
* Changed: upgraded project to KiCad 8.
* Fixed: improved routing to reduce traces with little clearance.

## v1.0.0
Released 16 November 2017

Highlights:
* Initial version.

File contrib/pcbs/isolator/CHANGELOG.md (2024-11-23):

# Changelog

## v2.0.0
Released 23 November 2024

Highlights:
* Changed: upgraded project to KiCad 8.
* Fixed: improved routing to reduce traces with little clearance.
* Fixed: part label placements.

## v1.0.0
Released 27 December 2017

Highlights:
* Initial version.

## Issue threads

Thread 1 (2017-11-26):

Serial number?

OleUrgast, 2017-11-26:
Hello,
its a great, that you can read and write the firmware via jtag. Many thanks for your work.

Do you know, where the serial number is coded? The hardware of warmwhite and whitespektrum Tradfri-Zigbee-module is the same. I have build lightstrip-controllers using the tradfrimodule and LogicLevel MosFETs. The most expensive part is the Tradfri-Bulp, making a whitespectrum controler twice as expensive as a warmwhite only.

So the cheapest way to build multiple whitespectrum controler would be to read the flashmemory from a whitespectrum and flash it to a warmwhite module taken from a cheap GU10 warmwhite. Of course, before flashing you have to change the serial number / mac to avoid confusion in the zigbee network.

The second use of your research is to clone tradfri remotes. The big disadvantage of Tradfri is, that you can only use one remote control for a bulp. If you connect a second one, the first one gets lost.
So if you connect a remote to the bulps of a room, cloning the complete flash (firmware and settings) to another remote will alow to use both remotes for the same lights. So I can use as many remotes in a room as I want. Here of course the serialnumber has to be the same.

Will the cheap jtag adaptor (about 3$ at eBay) do for flashing tradfree? or have i to use something special?

basilfx, 2017-11-27:
Hi @OleUrgast,

There are two possibilities: either the serial number is depends on the MCU, or it is embedded in the SPI flash. If it's the first, than every module will have its own unique serial number, which doesn't depend on the firmware. If its the second option, then you'll need to change that.

I haven't figured it out yet (working on the radio driver first), but I have used [this](https://github.com/basilfx/RIOT-applications/tree/master/spi_flash_identify) application to read the flash ID.

Regarding flashing: as long as it supports SWO/SWDIO/SWCLK + Reset, than it should work. I have used a STK3600 development board [set to debuggin mode](https://www.silabs.com/community/software/simplicity-studio/knowledge-base.entry.html/2014/11/24/using_an_efm32_start-H9Gy).

badblocks, 2017-11-30:
@OleUrgast:
You can have 2 remotes controlling one/group of lamps; learn one remote to a lamp/group of lamps and reset the second remote and then hold both remotes together and pressing both buttons inside the remote. Then they both controlling the same lamp/group of lamps.

OleUrgast, 2017-12-22:
@badblocks:
I tried that, but it didn't work.

The reason seems to be: To do the trick you described, the first remote not only have to be connected to some bulps, but also to a Tradfri gateway.
I use a hue bridge. The remote got it's zigbee settings via touchlink, so it can be used in parallel to the bridge.
In this configuration, the trick to copy the settings from one remote to another seem not to work. Its not surprising, as I discovered it seems impossible to touchlink a hue-connected Tradfri remote to an not already hue-connected bulp also.

So firmware/settings cloning via SWD seems the only option to use two or more Tradfri remotes in an hue environment.

spacesloth0x, 2017-12-27:
@basilfx Thank you for the effort you're putting into this. I read in the RIOT-OS pull request that you managed to read the flash. Would you be able to share that dump? It would seem the bulb state is stored in there, perhaps more.

basilfx, 2017-12-27:
@spacesloth0x I did not have read the flash contents yet. I only read the flash ID, to identify the chip used. But I presume it is just a standard flash chip, so you should be able to read it straight away.

darconeous, 2018-06-12:
@OleUrgast wrote:

> The big disadvantage of Tradfri is, that you can only use one remote control for a bulp. If you connect a second one, the first one gets lost.

I believe you are mistaken. I am currently controlling my ZigBee Light Link lights with multiple unmodified TRÅDFRI remotes. You can set this up using the Ikea TRÅDFRI bridge and the app (by moving the remote into the group), or you can do it when you commission a new remote:

1. Make sure you are starting with a TRÅDFRI remote that is already paired with all of the lights that you want to control.
2. Take the NEW remote that you want to add to the group and press the button four times. The LED will pulse six times.
3. Wait 10 seconds.
4. Press and hold the pair button on both remotes at the same time. The red LED on *both* remotes should start to glow or flash. Keep holding down the buttons until both lights finally go out—it will be around 10-15 seconds.

That's it. The remotes are now a part of the same group. Either remote will now control all of the lights. Removing or adding a light to either remote will automatically add the light to the other remote.

No need for all of the serial number hacking nonsense, which would almost certainly not do what you want.

OleUrgast, 2018-06-12:
As I said: I use a hue bridge. So I have to connect the remotes to the hue hub first, then touchlink  remote and bulb. Else touchlink a bulb to the remote will result in the bulb loosing connection to the hue-bridge.
But after connecting the remote to a hue bridge, touchlink seems to work with devices already connected to the hue-network only. Trying to touchlink any new or reseted device to the hue-bridge connected remote do not work. You have first to connect the targed device to the hue-net also. Than - and only then - you can connect hue-paired Tradfri remote and the hue-connected bulb by touchlink.
The same with a second remote: If you press the button 4 times, you reset the second remote - so its not connected to the hue-bridge. It will not react to touchlink from a hue-connected tradfri remote.

I tried the described way of copying a tradfri remote many times. Using a tradfri gateway it works fine. If a hue-bridge is used, it does not work at all.

Using the tradfri gateway is not an option to my setting, as in some cases I need the hue-dimmer for scenes (like the simple scene "all light off" set to the dim-low button at the dimmer beside the entry of the house, but also to select diferent colour-settings on the hue-lightstrips by pressing "on" multiple times) and to use the much better hue motion sensor.

As I already set up my complete house with a mix of tradfri remotes and hue-dimmers (only one tradfri remote in a group), I have not tried copying the flash yet. But next year I will upgrade my guesthouse also to zigbee - then I will giving copying the flash a try, as the tradfri remotes are less expensive and allow to control the colour (on Ikea colour bulbs) and the lighttemperature much more confortable as the hue-dimmer.

darconeous, 2018-06-12:
Trust me, I know what I’m talking about. I use a Hue bridge, too. Pressing it four times will cause the remote to forget the network. Pairing it back to another remote that is on the network will bring it back on the network AND put the remote on the same group. I’ve done this dozens of times.

I swear it works. I use several TRADFRI remotes with my Philips Hue setup, including in the configuration you say doesn’t work. My working setup is proof that it does work. I can make you a video if you still do t believe me.

Perhaps your remotes have an old firmware?

Sent from my iPhone

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

OleUrgast, 2018-06-12:
I see the missunderstanding.

You pair a remote (in german named "Fernbedienung" and a dimmer (in german simply called "Dimmer"). That works without issues in my setup also. It even works to pair dimmer and hue-bridge, remote and hue-bridge, than touchlink dimmer to light 1 and 2 and remote to light 2 and 3 - so light 2 is controlled by both controls (witch didn´t make sense with a remote, as it tongles so using the dimmer to turn on, it will result in light 2 going off and light 3 on when you tongle with the remote afterwards).

The problem is to pair two remotes ("Fernbedienungen" - the ones with the buttons) in a hue setup.
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
OleUrgast, 2018-06-12:
Yes, pressing the assisting dimmer button first (for a fraction of a second) works best. It is exactly the opposite of touchlinking a dimmer to the hue-bridge: There I have to press the dimmer button a little bit earlier as the "sending" hue bridge (I use the android app hue essentials for starting touchlink).

I now tried to connect an "unused" bulb (self-made tradfri lightstrip controller whitespectrum) using the dimmer. It worked. Simply connected the "bulb" to the dimmer using touchlink, then searched for new lamps in hue essentials - and it was found (as a GU10 colour spectrum bulb as this was the source I got the zigbee-controler from). Verry easy - I do not have to transport all new lamps to the hue-bridge any longer.
An other reseted bulb (prior already connected to hue) got touchlinked to the dimmer (and the remotes in the same group) but was not discovered by the hue bridge first. It seems it serial was "remembered" so it was not new, even as I had discarded it before. But after restarting the bridge it was discovered as new, so no real problem.

I may have found the reason, why copying remotes works for you but not for me. I remember last year the Tradfri-Gateway tried to update remotes with the same(!) firmware-version it already had. Maybe a "silent" update - some othe companys did simular in the past, updating the "same" firmwarenumber fixing minor bugs. But on my remotes this mostly failed. I did not thought about it much, as after the next firmware update the gateway got, it showed all remotes as having actual firmware...
I got no new remotes after that, so maybe while showing the actual firmware number they realy have a buggy pre-version.

So the "second" use for firmwarecloning (my first post) is gone. The first one stays: cloning the firmware from a whitespectrum zigbee-module to a cheap single-colour module - to make ww/cw lightstrip controller cheaper. But I already have build three controler, using only one now, so this it not urgend. It will get interesting, if my selfmade cheap Big-Fload-Project will work (using 4 normal cw-60x60 panels, 2 warmwhite, two coldwhite, building one big 130*130 panel (10cm space between the 60X60 for cabeling and electronic), as I will need at least 5 of the "Big-Float". But at the moment most of my time is spend to other projects

darconeous, 2018-06-13:
I'm happy I was able to help with at least one of your roadblocks!

> The first one stays: cloning the firmware from a whitespectrum zigbee-module to a cheap single-colour module - to make ww/cw lightstrip controller cheaper.

It's not clear to me what you are asking for, since it would seem that there is no longer any need for the location of the serial number. Are you asking for a copy of the color-temperature firmware, or are you asking for instructions on how to extract the firmware from (and subsequently reprogram) the modules? Note that it would likely not be legal to post an extracted firmware image on the internet, due to copyright.

I remember hearing from someone that IKEA did not apparently set any of the protection fuses, allowing the firmware to be read straight out of the chip—which is very surprising. I don't know if that is still the case. If I was IKEA I would lock that down ASAP.

----------

As a side note... [IANAL](https://en.wikipedia.org/wiki/IANAL), but I am suspicious of the legality of (from a copyright infringement perspective) of extracting proprietary firmware from one piece of hardware you own and subsequently running it on different hardware not intended to run it—even if the different hardware was purchased from the same vendor. Then again, I doubt IKEA would care unless you somehow started eating significantly into their profit margin (doubtful).

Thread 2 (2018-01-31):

"Devboard"'s Components' Values/Specs

git-marc, 2018-01-31:
Ref.: "Devboard"'s Components' Values/Specs

Dear Bas,

Thanks for all the information and files on TRADFRI-Hacking (Github):
An extremely helpful Package!

I would like to play & explore TRADFRI using your "devboard" schematics
but i did not succeed in finding further information on the components' specifications.
(“Devboard.kicad_pcb”, “Devboard.sch” and  their "Devboard bom file.csv” export did not reveal a hint)

May i ask which values you would recommend for the capacitors, resistors, switch?

I hope that you may find a spare second to reply
& look forward to hearing from you!

Best Regards!

git-marc, 2018-01-31:
...
"devboards" schematics connections using "Fritzing" ...
[https://picload.org/view/ddppoool/inquiry_tradfri-devboard.jpg.html](url)
...

basilfx, 2018-01-31:
The values are not very specific: take around 10µF for C1, 100nF for C2 and 1K for R1. They should work.

git-marc, 2018-02-01:
Thanks a lot for your reply, will try it!
...
updated “devboards" schematics (via “Fritzing”):
picload.org/view/ddwggoci/inquiry_tradfri-devboardok.jpg.html
_(link only seems to work when copy/pasted into browser's address field)_
...

Closed 2018-02-01.

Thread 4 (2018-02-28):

Memory sectors

Mes-ser, 2018-02-28:
I have question regarding memory sizes for bootloader / data / SimEEPROM - you wrote:
0x00000 - 0x03fff -> Bootloader + recovery image (16 KiB)
0x04000 - 0x????? -> Application data
0x????? - 0x3ffff -> Simulated EEPROM
And I looked on Datasheet for SimEEPROM and there was:
> For version 1, the EM35x and Mighty Gecko utilize either 4 kB or 8 kB of upper flash memory to store the simulated EEPROM
> For version 2, the simulated EEPROM requires 36 kB of upper flash storage

So depend on used version, we can assume correct memory addresses for different region <- But maybe i'm wrong?
it only takes to determine which version was used in this case -> it is possible to find used version?

I'm looking for that because I want to determine in which memory part Ikea placed model info etc.

basilfx, 2018-03-05:
If I look at the list of C files used, it includes `sim-eeprom2-internal.c`. That would mean it is using the 36 KiB of memory for the simulated EEPROM.

If I look at [this image](https://github.com/basilfx/TRADFRI-Hacking/blob/master/firmwares/ikea/led1650r5-1.2.214.png), the last part isn't exactly 4 or 8 KiB.

Closed 2021-01-11.

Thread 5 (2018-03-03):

Output via UART

jonathanschneider, 2018-03-03:
Hi,

I have a dimmer with an ESP8266 which I would like to replace with the ZigBee module I took out of a Tradfri bulb. Does the Tradfri module output anything via UART? If so, which pins are used for UART?

Any help would be appreciated.

sorenfalch, 2018-03-04:
Hi Jonathan!

I'm thinking about doing the same thing (have also bought a couple of GU10's for the same purpose).
I found this video which I found quite informative. Maybe it can also help you:

https://youtu.be/bNS_fINyaQE?t=43m15s

BR, Søren

basilfx, 2018-03-05:
As far as I know, the pins do not output to UART. What makes it harder is that the EFR32 have flexible pin mapping: any GPIO could be UART :-)

MattWestb, 2021-06-22:
@jonathanschneider If you can flashing one new bootloader then you can flashing one Zigbee Controll Bridge firmware and you have CLI for sending and receiving all commands you like then the device is in one network.

Example: Putting one "on" command in the buffer (ZCL command). Then sending the buffer to group 0x0006 (mulicast send command).

Closed 2020-01-11.

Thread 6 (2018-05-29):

Making a commit (LED module teardown)

ludwo88, 2018-05-29:
Hi @basilfx,
I would like to make a commit to your project. I made a teardown of the 30W Trådfri LED driver module. So far I have a bunch of pictures and made some basic research on the components used.

I am not able to create a pull request or upload files. Could you make a branch for me? Thanks

basilfx, 2018-05-29:
Hi @ludwo88, you should be able to fork this repository, clone that fork, make the changes and push it. Once you visit this repository, it should propose you to create a PR. There should be some help on [this](https://help.github.com/articles/creating-a-pull-request/) page.

ludwo88, 2018-05-29:
Great, after the fork I was able to make changes and GitHub offered to create a PR which now shows up here as well. Thanks for the tip. I am quite new to git repositories...

Closed 2018-05-29.

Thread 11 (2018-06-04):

Antenna of breakoutboard ON breakoutboard

oliv3r, 2018-06-04:
Looking at the latest 3D rendering on the breakout board for the ZLL module, I notice the antenna is sitting ontop of the PCB. Would it not be more helpfull to move the antenna offboard, as is done with the led drivers? (e.g. have it stick out/no PCB underneath). The only real blockage would be the reset button which in turn could move down a little bit between the pin-headers or to the bottom left where the led also lives.

Further more, would it be a good idea to put through-hole pads underneath the ZLL module? E.g. that way we can either solder the module directly onto the carrier board, or solder pinheaders onto the ZLL module and headers onto the carrier board to make it swapable (or even put pins on the carrier board and 'squeeze' the ZLL module temporarily in between.

oliv3r, 2018-06-11:
why not have the antenna stick out however? All the modules from IKEA also do this from images I have seen. Granted, performance is not important at all herein.

darconeous, 2018-06-11:
Copper fill below the antenna would have killed the performance. It was a good idea to remove it.

It's not clear how much having the antenna against the bare PCB would have. It would likely be minimal, but not zero. For a break-out board intended for testing purposes, I think it is more than sufficient.

Then again, I don't think these antennas are tuned with any great precision. I've noticed a very large variance of sensitivity across the handful of devices I have purchased.

I'm curious though why you are going for this sort of design with the break-out board. Wouldn't it be nicer to have a board which you could just plug into a breadboard? You could still keep the debug headers...

darconeous, 2018-06-11:
Have a look at the copper keep-out zone from the remote:

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

It's much larger than your keep-out zone.

oliv3r, 2018-06-13:
I was thinking something like https://gitlab.com/olliver/TRADFRI-Hacking/raw/ICPSLC24-10NA/teardowns/ICPSLC24-10NA/controller_top_01.jpg was my thought :)

as for the pinheaders I think having it breadboardable/pluginable just depends on where you solder the pins, no?

darconeous, 2018-06-13:
> as for the pinheaders I think having it breadboardable/pluginable just depends on where you solder the pins, no?

The more narrow the board, the better it will work with a breadboard.

oliv3r, 2018-06-14:
actually, we can also find this in the FCC submitted manual:
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

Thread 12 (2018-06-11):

Prototyping board thoughts

darconeous, 2018-06-11:
I had a look at your TRÅDRI dev board, and I had a few comments and suggestions that I think would allow the board to be more versatile and more generally useful:

* Redesign the board in such a way that allows it to be plugged into a breadboard if the headers are soldered facing down instead of facing upward.
* Remove the reset button. If you need a reset button for a project, it is easy to add on a breadboard. Removing the button should allow you to shrink the size of the board considerably, allowing it to more easily fit on a breadboard.
* Remove the power LED. It is easy to add a power LED on a breadboard, and having a LED on this board will throw off power measurements.
* Remove the bypass caps. All of the capacitors that are required by the EFR32 datasheet are [already integrated into the module](https://raw.githubusercontent.com/basilfx/TRADFRI-Hacking/master/images/front.jpg).
* In order to be as conservative as possible, remove all of the copper fill directly under the module. Copper fill on the other side of the PCB might be fine as long as it is kept far away from the antenna, but many modules like this explicitly forbid copper fill anywhere under them.
* Leave the antenna hanging off the end of the board, [as seen here](https://user-images.githubusercontent.com/39415298/40666150-5baa04f8-635f-11e8-930a-1bde7d409a8c.jpg)
* Keep the debug headers. Those are often useful, and having to always hook them up manually on a breadboard would be a pain.
* Shrink the board to be as small as possible, to help make usage with a breadboard more easy.

Closed 2020-01-11.

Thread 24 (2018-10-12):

upload OTA rgb bulb firmeware to radio modul from a remote control

NetHans, 2018-10-12:
Hello,

I have taken the radio module from a Tradfri remote control. Is it possible to play the functions of the RGB bulb on this wireless module by means of the OTA firmware? Or someone has a full dump of the firmware of the RGB bulb?

oliv3r, 2018-10-18:
I don't know what you consider 'full' dump of the firmware, but in the firmware dir there are some dumps/update files.

oliv3r, 2018-10-24:
ah right, well a few levels up is a JTAG dump of the full firmware, that bas was able to read and restore. so there's that.

oliv3r, 2018-10-24:
obtaining all firmwares from the devices is a different challange of course :)

basilfx, 2018-10-24:
I was able to dump a firmware, overwrite it with something else and load it again using the steps mentioned [here](https://github.com/basilfx/TRADFRI-Hacking#software-used). Like @oliv3r, you need to have a dump of the full firmware first ;-)

NetHans, 2018-10-24:
I have now put up for testing the firmware led1650r5-1.2.214.bin. The connected LED behaves as expected, but I can not find the chip through the gateway.

In the folder of the firmware I also found the file led1650r5-1.2.214.strings. Can it be that important configurations are included here? How can I first save the configurations of my chip and how can I then upload the led1650r5-1.2.214.strings to the chip?

basilfx, 2018-10-25:
The strings file is just a dump of all the strings that can be found (using `strings <filename.bin>`). It's of no use, apart from hacking the firmware.

You probably need the contents of the SPI chip as well. However, I never attempted to dump it.

efuturetoday, 2018-12-04:
I am also interested in a full dump of the flash and SPI-chip-dump. Same idea here: Turning the remote into a RGBW ZigBee Controller. I found an image of the PCB of the RGBW bulp: https://i.ibb.co/V3Gb5qT/3xtUrUX.png seems to use another kind of Zigbee-Module-Board. Maybe same CPU.

oliv3r, 2018-12-04:
looks like the same board but with the metal cap removed ... check out https://diystuff.nl/tradfri/tradfri-zigbee-light-link-module/ for detailed pictures ...

efuturetoday, 2018-12-04:
Agree should be same hardware - just different Layout even the GPIO pins count is the same. Just an Idea: Riot-OS is supported from now. Can we just dump the flash with a simple firmware over serial? And Flash the same dump with it Ingo a different device. After this just flash the original firmware with JTAG. Should work?

efuturetoday, 2019-03-01:
**Update:** I finally got the dimmable white bulp 1000lumen software flashed on the remote. For pairing i used this instruction:

>  I then reset the bulb by turning it on and off 6 times. Once that was done I initiated a search for a new light from the Hue app without success. I then initiated another search via the Hue app, and while that search was running, I turned the light off and then back on again, and the Hue app found it.

I also did some flash dumps and it seems that the app just uses the simulated eeprom for persisting data. Hopefully i made someone happy out there - you can turn a 5€ remote into a hue compatible controller.

slm85kbh, 2019-10-15:
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

I'm trying the opposite, can you elaborate on how you succeeded in this? I've tried via STLink-v2 and openocd, but it gives me an "Unknown MCU Family"

CableCatDK, 2019-10-15:
You might find the infomation in the guide usefull, even if it in Danish:
https://drive.google.com/drive/folders/1SMhPC1echgKWlc-W4N89JKZ2KiJ_H_ZD

It tells how to use JTAG to dump or flash the ZigBee module.

slm85kbh, 2019-10-17:
Tak CaleCatDK, det var en kæmpe hjælp! Det er på dit pcb design jeg roder :)
Danish was not an issue ;)
And I managed to apply the changes to a normal pc with stlink-v2, and now I have a working remote with the zigbee module from a bulb....

CableCatDK, 2019-11-30:
> And I managed to apply the changes to a normal pc with stlink-v2, and now I have a working remote with the zigbee module from a bulb....
Can you please describe how you got ST-Link v2 working. I just got one now, and I want to make a guide for windows users.

MattWestb, 2020-06-29:
Normally for bulbs share the same firmware but different model / setting its stored in the userdata that not being erased with normal internal flash erase.
From GDB:
(gdb) info mem
Using memory regions provided by the target.
Num Enb Low Addr   High Addr  Attrs
0   y   0x00000000 0x00040000 flash blocksize 0x800 nocache
1   y   0x0fe00000 0x0fe00800 flash blocksize 0x800 nocache
2   y   0x0fe10000 0x0fe12800 flash blocksize 0x800 nocache
3   y   0x20000000 0x20008000 rw nocache

Reg 0 = Flash (256K)
Reg 1 = Userdata (2K)
Reg 2 = Lockbits (10K)
Reg 3 = Ram (32K)

More info with SWD flashing: [Flashing the ICC-1 Module](https://github.com/MattWestb/IKEA-TRADFRI-ICC-A-1-Module/tree/master/Flashing-MG#mem-regions)

sauer-m, 2021-08-17:
Hi there,
did someone has a complete dump of the fyrtur blind? 😬

MattWestb, 2021-08-18:
I think byes of them is not so "hacky" and they is little more expensive then the cheapest bulb.

You can trying "extracting" the firmware from the OTA file the is rapped with one signing and only need finding the start of the code part and cutting the heeding and ending signing part away then all the code is not encrypted.
I think (without knowing) that the user data is only changing the name of the device but i cant being sure (with the On/Off / Open/Close button its changing the device type and how the device is working with the same firmware).

I have seen scripts that is extracting the metadata from one OTA file and then can extracting the APP (the main flash part) from it but i cant finding it from the moment.

honglihu1986, 2022-07-27:
I have a JAZZDANS,but i don't know how to dump of the firmware, it's can't connect to BLINK with SWD.

MattWestb, 2022-07-27:
If its the classic IKEA ICC-A-1 Zigbee module is shall working OK with one no original J-Link  probe like or Black Magic Probe or other SWD probes.
Then JAZZDANS is not sold in EU i cant saying if IKEA have updating the Zigbee module to the new one (Silabs original MGM210LA22JNF2) and if its you need one real J-Link for reading and writing the flash in the chip then its have higher security that is not working with other SWD probes.

Can you posting one photo of the PCB with the Zigbe module ?

honglihu1986, 2022-07-29:
https://drive.google.com/file/d/1KmIRXP6XX3yp3b8BulPCjg8f_wANTR3K/view?usp=drivesdk

MattWestb, 2022-07-29:
Its one ICC-A-1 module (normal "old" one) so shall being easy dumping and flashing !!

06 | PF0 | SWCLK
07 | PF1 | SWDIO
11 | VDD |
12 | GND |

shall being enough.

Pin out from FCC https://github.com/MattWestb/IKEA-TRADFRI-ICC-A-1-Module/tree/master/teardowns/ICC-A-1

Always dumping the man flash (0) **and** user data (1) !!

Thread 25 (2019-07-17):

Convert module from bulb into remote control

CableCatDK, 2019-07-17:
I have a project where I modify a remote control into a wall switch. Right now I harvest the module from a original remote control. But that is both expensive and harder than extraction it from a bulb.

Therefor I would like to reprogram the bulb firmware into a remote control. I have done this over OTA. But the switch only works if the module is directly joined with a bulb. If the module is joined with a gateway, it still appears a bulb.

Therefor I would like to use JTAG to clone a firmware from a remote to a bulb*. But I have zero experience with JTAG. I have borrowed a AVR Dragon, which I don't know how or if it can be used. I consider buying a JLink device.

Which JLink device would you recommend to buy for this purpose?

*There are probably some IDs like ZigBee MAC address that need to be unique.

Link to project (in Danish): http://www.thingiverse.com/thing:3655354

Closed 2020-01-11.

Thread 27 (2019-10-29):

Additional item E1745 TRADFRI Motion Sensor

OneOfTheInfiniteMonkeys, 2019-10-29:
Additional item E1745 TRADFRI Motion Sensor
Uses same Zigbe board external connection points as other modules, Though later version having same CPU. Zigbe board marked Draco1.0_105°C
Uses:
  2 CR2032 batteries for 6 volt operation
  E931.96B Infra red motion sensor interface device
  LHI 968 – Sensor Motion, Pyroelectric (presumed as no markings)
  TCA9535 Low Voltage 16-Bit I2C and SMBus Low-Power I/O Expander (for buttons and LEDs)
  3 tactile switches
  5 LED's
  ZIGBEE Board
    EFR32 MG1P132GI Blue Gecko Series 2 Bluetooth® Low Energy (SoC)
    I4BEB2 P1J552 EEPROM
    TXC Oscillator T384 SMD

PCB 2018-06-05
D-SS-X2-01-A-V2.1

A little different to this module https://github.com/basilfx/TRADFRI-Hacking

CableCatDK, 2019-10-29:
The Draco module is used in all new TRÅDFRI products. I have seen it in the new remote and in the signal repeater. When programming it there is no difference.

See also: https://wiki.iptables.dk/TR%C3%85DFRI_wall_switch#Extract_the_TR.C3.85DFRI_ZigBee_module

OneOfTheInfiniteMonkeys, 2019-10-29:
Is it possible to change the code on the E1745 TRÅDFRI motion sensor to have it work with Philips Hue?

basilfx, 2020-01-11:
It seems that this is the ICC-1-A module that I now have described in the README.md as well.

The only difference I found (so far), is that PF3 is now unavailable, and used to power the SPI NOR Flash.

EpicLPer, 2020-01-15:
What component actually controls the time setting on the E1745? I'd love to flash a custom firmware on that thing with just a 2-5 second "ON" state when there's movement, not 3 minutes minimum. I've already added the sensor to my Zigbee2MQTT network and read data from it via Home Assistant but the 3 minute timer doesn't allow me to play around with it much.
I've taken one of the sensors apart but I doubt I have the required hardware to read the contents of the Zigbee module... Not a "hacker" myself in that regard, max. I got is a serial to USB adapter :P

Closed 2020-01-11.

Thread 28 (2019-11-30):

Custom Full Stack

sorenfalch, 2019-11-30:
Hi Community!
Is there any work going on developing a full custom stack (eg. based on http://zboss.dsr-wireless.com/), a decompiled firmware stack, or otherwise? Would be fantastic to e.g. customize the RCU FW to control two groups of lights, etc (like two on/off remotes in one), etc.. make it control custom projects, etc...
Thanks 😊

basilfx, 2020-01-11:
Not that I am aware of, but that looks promising. I'll keep this issue open if anyone is working on this.

benemorius, 2020-02-11:
There's been at least some indirect work on this and it's actually not as far away as it seems.

I've been updating the zboss stack to support ZLL and Riot [here](https://github.com/benemorius/zboss). I've tested it with kw41z and at86rf233 and it's functional enough to do a zll pairing and control on/off/color/brightness. I need to get another sacrificial tradfri device to start testing it with efr32 which is what tradfri devices use but [RIOT-OS/RIOT#9212](https://github.com/RIOT-OS/RIOT/pull/9212) looks promising.

Basically a full stack replacement is a reality as soon as someone gets Riot's efr32 radio driver working with the zboss stack. It may be working already but I won't know until I test it.

Here's a demo so I don't look like I'm talking out my ass:
https://imgur.com/cdZd9je

kaibeckmann, 2020-02-11:
Thats sounds interesting.
Do you use the RIOT at86rf233 driver / MAC layer or the one of the zboss stack?

If you are using RIOTs 802.15.4 layer, theoretically ZigBee and 6LowPAN could run in parallel (might be useful for dotdot).

benemorius, 2020-02-13:
It was easiest to just use the zboss mac for now. It sends packets by calling `gnrc_netapi_send()` with a full 802.15.4 header already filled, and it receives them by putting the interface into raw mode (`ifconfig 7 set raw`) and calling `gnrc_netreg_register(GNRC_NETTYPE_UNDEF)`.

Indeed the Zigbee stack and 6LoWPAN stack run just fine along side each other already. To accomplish that, I just added a hack to `gnrc_netif_ieee802154.c::_recv()` to bypass raw mode for the panid of my 6lowpan network and I suppose the better way of doing that would be to register each panid for whichever stack the packets should go to.

benemorius, 2020-05-28:
> Basically a full stack replacement is a reality as soon as someone gets Riot's efr32 radio driver working with the zboss stack. It may be working already but I won't know until I test it.

Turns out it's working already, though I have some zboss and riot bugfixes on the way to make it work better. Updates soon.

> If you are using RIOTs 802.15.4 layer, theoretically ZigBee and 6LowPAN could run in parallel (might be useful for dotdot).

I had to drop dual-stack on tradfri for now to stay within the 32k ram. It was only off by a few k and I already know a few places in zboss where I'm wasting lots of ram so I'm actually pretty sure that Riot can comfortably fit both zigbee and 6lowpan stacks on tradfri. I have no idea yet about BLE though.

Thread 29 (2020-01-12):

Pinout of module when using it as a remote

CableCatDK, 2020-01-12:
Here is the pinout of the 5 button remote.
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

Here is the pinout of the ON/OFF remote, if you flash its firmware to the module. The LED pin is not available.
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

Buttons are pushed by pulling the pin the GND with a 487 ohm resistor. Except paring, which is pushed by short to GND.

LED is powered by a 2N7002ET MOSFET.
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

basilfx, 2020-01-13:
Thanks for the information!

Can you confirm its part number? The [E1524](https://github.com/basilfx/TRADFRI-Hacking/blob/master/PRODUCTS.md#e1524-remote-controller) remote is already in the overview, but it seems that ikea now sells it as the E1810 (not sure though).

CableCatDK, 2020-01-14:
The new remotes contains the Draco module.

MattWestb, 2021-06-22:
Is some one knowing wot the TP1 and TP2 is connected to the module ?
I was hoping its the debug pins for SWD so not need using brute force for dumping the firmware but i have not testing it then i have not opening my remotes and dont like destroying them.

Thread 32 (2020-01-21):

Status of wireless peripheral support?

gnbl, 2020-01-21:
Is there any information about the support of the wireless functions (Zigbee for Tradfri, but BLE and others seem to be supported by EFR32MG1 as well) by your efforts (https://github.com/RIOT-OS/RIOT/blob/master/boards/ikea-tradfri/doc.txt) or the RIOT project in general?

<hr>
Maybe you could add some info to https://github.com/basilfx/TRADFRI-Hacking#custom-firmware (toolchain, debugger hardware, SDKs etc)?

basilfx, 2020-01-23:
There is some work done on the radio driver for the EFR32 for RIOT-OS: https://github.com/RIOT-OS/RIOT/pull/9212. It's based on RAILlib, that I presume is also used for the original firmware.

gnbl, 2020-01-23:
Thanks. That effort appears to have "died", so effectively there is no Tradfri radio support for RIOT and the hardware can only be used with the ARM MCU core.

kaibeckmann, 2020-01-23:
> Thanks. That effort appears to have "died", so effectively there is no Tradfri radio support for RIOT and the hardware can only be used with the ARM MCU core.

It's not completely dead. If you want to try it, I can rebase it to the current RIOT version. But be aware, there is one very annoying and persistent bug with the 6LoWPAN fragmentation...

We also have a "version" for the NimBLE support of RIOT in a private repo, but currently no resources to bring it upstream to RIOT.

gnbl, 2020-01-23:
Thanks for the offer, but no need - unless there's an easy-to-use toolchain or a project to reuse the tradfri remotes as BLE controllers (Simplicity Studio code examples or generator), this is currently too involved for me.
I think this project's readme should point out that the hacking is somewhat limited.

Closed 2021-01-11.

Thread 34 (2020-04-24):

ICPSLC24-10NA in 30W dimmer

nica-f, 2020-04-24:
I just opened a 30W LED dimmer (the larger gray box) and found inside a ICPSLC24-10NA Rev1.0.0 module, which according to your findings would be the 10W LED dimmer. So either the -10NA can also do up to 30W or I got a very "very special" model from my Ikea shop :-)

CableCatDK, 2020-04-24:
It is the same module that is both in the 10W and 30W version. So if you just want the module, you can save money and buy the 10W version.

Se also this video: https://youtu.be/qQTJMTNVd40

nica-f, 2020-04-24:
Ah, good to know, thanks!
I just reported this as an issue since the repository with the pictures and schematics points out the -10 and -30 version as 10W and 30W...

Closed 2021-01-11.

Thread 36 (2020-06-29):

New GU10 bulb disassembling

MattWestb, 2020-06-29:
Have disabled one LED1875R5 without heating the lens with very small and hard flat screwdriver and working well and no cracking in the glass.
I have one LED1737R5 that was falling down and the glass its very broken so i want to change the glass with the LED1875R5. The problem was not getting the power pins losing. In the end I was using one gas heat gun and heating the connectors of the GU10 and trying getting the pins inside getting loose but was needing very mutch heating and the soldering on the PCB was loosing from the pins. Then taking the pins out from the GU10 connectors from inside. Resoldering the pins it's no problem but getting the PCB back in the glass with the pins in the GU10 connectors.
I can see on your photos than you have managed getting the PCB out from the GU10 glass without destroying the glass and PCB.
It's the PCB pins soldered inside the GU10 connector or crimped in place ?
Then I have getting the LED1737R5 out without destroying it making it some more photos and dumping the firmware. and userdata and measuring the PSU voltage to the LEDs
Thanks in advance ! !
Mattias

basilfx, 2020-07-14:
The PCB pins are unfortunately crimped to the case. So it's quite hard to get them out. But it remains a cheap source to get the modules out ;-)

MattWestb, 2020-07-14:
Thank for sharing info !
Than I trying making the criping lager with a small steel neadel so i can putting the PCB from the LED1737R5 (with re solided pins) inside the good case.
Bay the way i having the one module up and running (in alpha state) as Zigbee coordinator under Tasmota after brickiing 2 ICC-A-1 modules with J-Link (bootloader writing app with wrong offset and corrupted peripheral and lockbits area).
I hope you and the other in the community its keep working on the EFR32 for the RIOT-OS project, its looks very interesting !!!

Closed 2021-01-11.

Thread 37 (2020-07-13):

Dev board

arcidodo, 2020-07-13:
Hi,

Can I order an dev board? Or do you know an good shop
To create one? I live in the Netherlands.

Greeting Arco

basilfx, 2020-07-14:
There are many PCB services that can print a board for you. It can be as simple as uploading the Kicad files. My favorite PCB service is Aisler.net ([project link](https://aisler.net/p/EZPFEBPX)).

Do note that the current development board is not perfect. You might want to consider #18 by @oliv3r.

arcidodo, 2020-07-14:
thx

oliv3r, 2020-07-14:
@basilfx omg welcome back :D yeah I do have to do a small fix on the devboard, that i'm planning on doing ... but time :(

Closed 2020-07-14.

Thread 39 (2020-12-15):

New module in the GU10 RGB

CableCatDK, 2020-12-15:
IKEA product number: 804.392.28 (unrelased)
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

CableCatDK, 2020-12-15:
Text on RF shield:
MGM210L022INF2
Model: MGM210L22F
1934A01HB2

https://fccid.io/QOQMGM210L/User-Manual/User-Manual-4211003

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

CableCatDK, 2020-12-15:
The module can be bought here: https://dk.farnell.com/silicon-labs/mgm210la22jnf2/lighting-module-2mbps-3-8v/dp/3249880
Data Sheet: http://www.farnell.com/datasheets/2865974.pdf
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

basilfx, 2021-01-11:
Thanks for the heads-up. I have bought that light and torn it down. I'll add it to the repo.

basilfx, 2021-01-11:
I have added some information about this module and the product It is in. Thanks!

boelle, 2021-08-18:
@basilfx will check this, but did you add it as a kicad thing so we can use it without having to draw it up from scratch?

Closed 2021-01-11.

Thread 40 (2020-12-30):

Add a things section

kollokollo, 2020-12-30:
I have found some 3D printable objects beloging to the TRADFRI system. maybe one should add a new folder caused things to this repository. Or maybe just a file with a list of things and links to thingiverse or the like.

Here are some already:

https://www.thingiverse.com/thing:2254364 Ikea TRÅDFRI (TRADFRI) remote UK light switch holder

https://www.thingiverse.com/thing:2195340 IKEA - Mandal - Tradfri remote holder + glass holder

https://www.thingiverse.com/thing:3254038 Foot IKEA Tradfri Detector

https://www.thingiverse.com/thing:3594356 Ikea Tradfri motion sensor shelter

basilfx, 2021-01-11:
I want to have this repository focus more on the hardware side of the products. I don't think it's a bad idea, I just don't know how 3D printed parts would fit in this repository.

I'll close this issue for now.

Closed 2021-01-11.

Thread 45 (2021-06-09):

What's a good way to attach an external antenna to the repeater?

mortenmoulder, 2021-06-09:
I disassembled one of the repeaters and found an ICC-A-1 inside. I was hoping I could increase the range, by attaching an external antenna, but I'm not sure how one would do that (I have little to no experience with antennas).

I do have a couple of different antennas laying around, though. From good routers and some ESP32 ones, as well as some for LTE routers.

I am willing to sacrifice basically any of these antennas, by trying to attach it to one of my IKEA repeaters. However, to my knowledge, simply adding an antenna won't do anything, because the transmit power is still the same.

I want to get the maximum range possible from one of these. How would I go about doing that?

MattWestb, 2021-06-10:
The ICC-A-1 module RF part is tuned for the PCB antenna so its no 110% match for one external one.
You can tying cutting the PCB line after the golden part that is exposed and soldering the antenna there and finding so good grounding for the grout path but i think you is getting the resolute that many with CC-2531 sticks have that the  internal antenna is working better then the external because its not being matched to the external 50 Ohm antenna.

ESP32 antennas is working on the same frequency = OK is good quality.
Other LTE, 434 and so on it not matched and is very likely working very bad.

If you is having one device with the new Silabs module you can changing the antenna path and using the pads for the external antenna and all is OK and very power full !!

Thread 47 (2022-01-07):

possibility to emulate tradfri blinds

comlit, 2022-01-07:
hi
I recently connected my somfy rts blinds to my smart home. I can now control it through http requests. I got some Ikea smart home products already installed in my home, so I wondered if it is possible to emulate a tradfri blind and connect it to my existing work so that in the end it would be possible to control the somfy blind through the Ikea app. From what I saw in this repo it seemed as this would be possible. I would like to hear your thoughts and suggestions on this, since I have got no clue what I'm doing :). thanks

basilfx, 2022-01-12:
Emulation would mean that you would create some piece of hardware that behaves exactly as the IKEA blinds.

It would be much easier to see how the IKEA blinds work, and how you could hook it up to your existing blinds. So whenever the motor moves, route that signal to your existing blinds. You need to reverse-engineer the existing IKEA solution, to see what signals are sent to the hardware that physically controls the blinds.

Easy answer, hard(er) in reality ;-)

CableCatDK, 2023-05-23:
90% rabatt, that is something. I only got 32% rabat, and additional 200 DKK from a coupon.
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

MattWestb, 2023-05-23:
It was 50% off but only the battery was in the package no remote, mounting, changer instructions and so on and it was badly scratched but working OK.
I was asking for guarantee and the rest of the missing things and then was not saying and good things so i was saying its was for the trash but im interested in the Zigbee module and was getting one new price without guarantee.

honglihu1986, 2023-05-24:
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

MattWestb, 2023-05-24:
@honglihu1986 You must have some connection problem the the MG1P chip then it cant being debug locked only writ protecting flash pages.
Did you disconnect the motor and the battery so they cant interference with the debug connection ?
 Here is the `TREDANSEN block-out cellul blind` user data [E2022-UD.zip](https://github.com/basilfx/TRADFRI-Hacking/files/11550556/E2022-UD.zip) and it shall working with one normal IKEA bootloader plus rolling on extracted OTA file like we was doing with Symfonosk 2.

Also UD is only name is overrided and no hardware parameter so they is using the same motor controller board and software on it = very good.

honglihu1986, 2023-05-24:
Thank you very much for the guidance, I don't understand how to scroll on the extracted OTA file, I flashed this user data into an outlet, Home smart 1 shows a roller shutter, but it can't OTA into a blind, it shows the latest firmware.

honglihu1986, 2023-05-24:
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

MattWestb, 2023-05-24:
Ops its little more advanced.
The OTA file is rapped with metadat that need being removes and you is getting one EBL/GBL file that can being flashed with commander.
I must look for the ext instruction but you can doing it with zigpy.cli.

If you have dumping the main flash of one blind its the easiest way only flashing it on one new module and only need the user data for working OK and can being OTA updated without problems.

MattWestb, 2023-05-24:
For dumping MG1P modules you can using my old guide that is not complete but is working and explaining most things https://github.com/MattWestb/IKEA-TRADFRI-ICC-A-1-Module/tree/master/Flashing-MG

MattWestb, 2023-05-24:
By the way one updated firmware for all blinds in in the pipe.
https://csa-iot.org/csa_product/connected-roller-blind/

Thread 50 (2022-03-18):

Converting ICPSLC24-10NA to 12v

Treantno, 2022-03-18:
I have been hacking around converting to make it run on 12v. With a 12v input and light load it sort of works. But a log led strip would not turn on. Changing R9 from 270k seems to do the 12v conversion trick, for now I have added a 230k in parallel (making it 124.2k). R9 should ideally be 125k for a 12v conversion.

pkonowrocki, 2022-10-05:
@Treantno What does "sort of works" mean? And how long does the strip have to be to not turn on?

Treantno, 2022-10-05:
I have not experimented with different lengths. The issue is that the overload  protection is based on detecting low input voltage to the switch, and if it's set just bellow 12v and with light load it will turn off due to low input voltage. The resistor change lowers the threshold to work fine with 12v input.

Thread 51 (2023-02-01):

Reduce the polling rate from the motion sensor

ppamorim, 2023-02-01:
Hi.

Would be possible to patch the motion sensor board to change the polling rate? I would like to make my toilet lights turn off faster.
I heard that to save battery the device sleeps for 3 minutes. I would like to reduce it, even if I need to install another battery.

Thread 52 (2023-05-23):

Anyone have a åskväder?

honglihu1986, 2023-05-23:
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

CableCatDK, 2023-05-23:
I have one, but I don't intent to destroy it.

honglihu1986, 2023-05-23:
I can not find the OTA file.

MattWestb, 2023-05-23:
TF is having it in its feed but i dont knowing if its working then i have not testing it on my device.
<html>
<body>
<!--StartFragment-->

10078247 | 0x110D 4365 | ASKVADER on/off switch (E1836) | 3 ZB3 | 1.0.002 1.0.32 ✅ | 🔲
-- | -- | -- | -- | -- | --

<!--EndFragment-->

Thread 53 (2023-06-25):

Is network cloning possible from gateway?

vuokko, 2023-06-25:
Hello,

My current situation is that my old tradfri gateway is dying. It has had twice open surgery on my bench.
The other problem is that there is no migration path. Re-pairing everything would be irritating task.

I'm probably going for SMlight's slzb-06 and home assistant, so this could be little bit offtopic.

Everyone is repeating the gospel, migrating without re-pair isn't possible, but no-one isn't really telling the reasons. Is here someone who can give some answers why it wouldn't be possible.

My limited understanding is that with some steps it is possible.

1. Join to the network
2. Learn long and short network names
3. Map the network devices
4. Ask the direct communication keys to all found devices from key store. This may be something where I missed something important.
5. Copy network settings and keys to our new gateway
6. Pull the plug of the old one
7. Turn on the new one.

Is there something I missed? Another protocol on top of the zigbee which makes life hard?

MattWestb, 2023-06-26:
The TF network working mode is one Zigbee Light Link = every controller is responsible for adding devices and allocation of network addresses and groups and the TF GW is one _Zigbee Controller bridge_ as device type = ti can communicating with all devices in the network and also controlling them but cant manager the network security then its coming from the network was started and cant being changes and if it was you need changing it in every device routers and controllers that is not possible.

DIrigera, Z2M and ZHA is running in Zigbee 3 centralized security mod (Trust center) with one coordinator that is manager the security and all is centralized so you is having most of the information of the network in the coordinator and can also manage the network from it.

You can adding one device with classic paring to TF GW and getting the network credentials (its how to getting the network key for sniffing with wireschark) but you cant changing the network parameters in all devices have getting then joined the ZLL network then it was sett with touch link commands then it was joining it and can only being sett then joining the network.

Not working parameters that you cant changing in device is bindings for reporting and also network addresses and group you is gonna getting conflict in the future that all devices is have there range set with TL and cant being changed.

You need reading some papers how ZLL / Zigbee 3 network forming and security is working then its complete different methods and cant being changed on the fly.

Silabs is having some good ones but i dont remember the name of them.

Recommendation set up / forming one new network with your TI coordinator and adding routers from near it and out and then adding end devices to the ideal parent routers and you is getting one good mesh network.

vuokko, 2023-06-26:
Thanks for a good answer. I didn't know about ZLL before and learned a lot already. And now I know what to study and maybe learn a way how to work with both of them.

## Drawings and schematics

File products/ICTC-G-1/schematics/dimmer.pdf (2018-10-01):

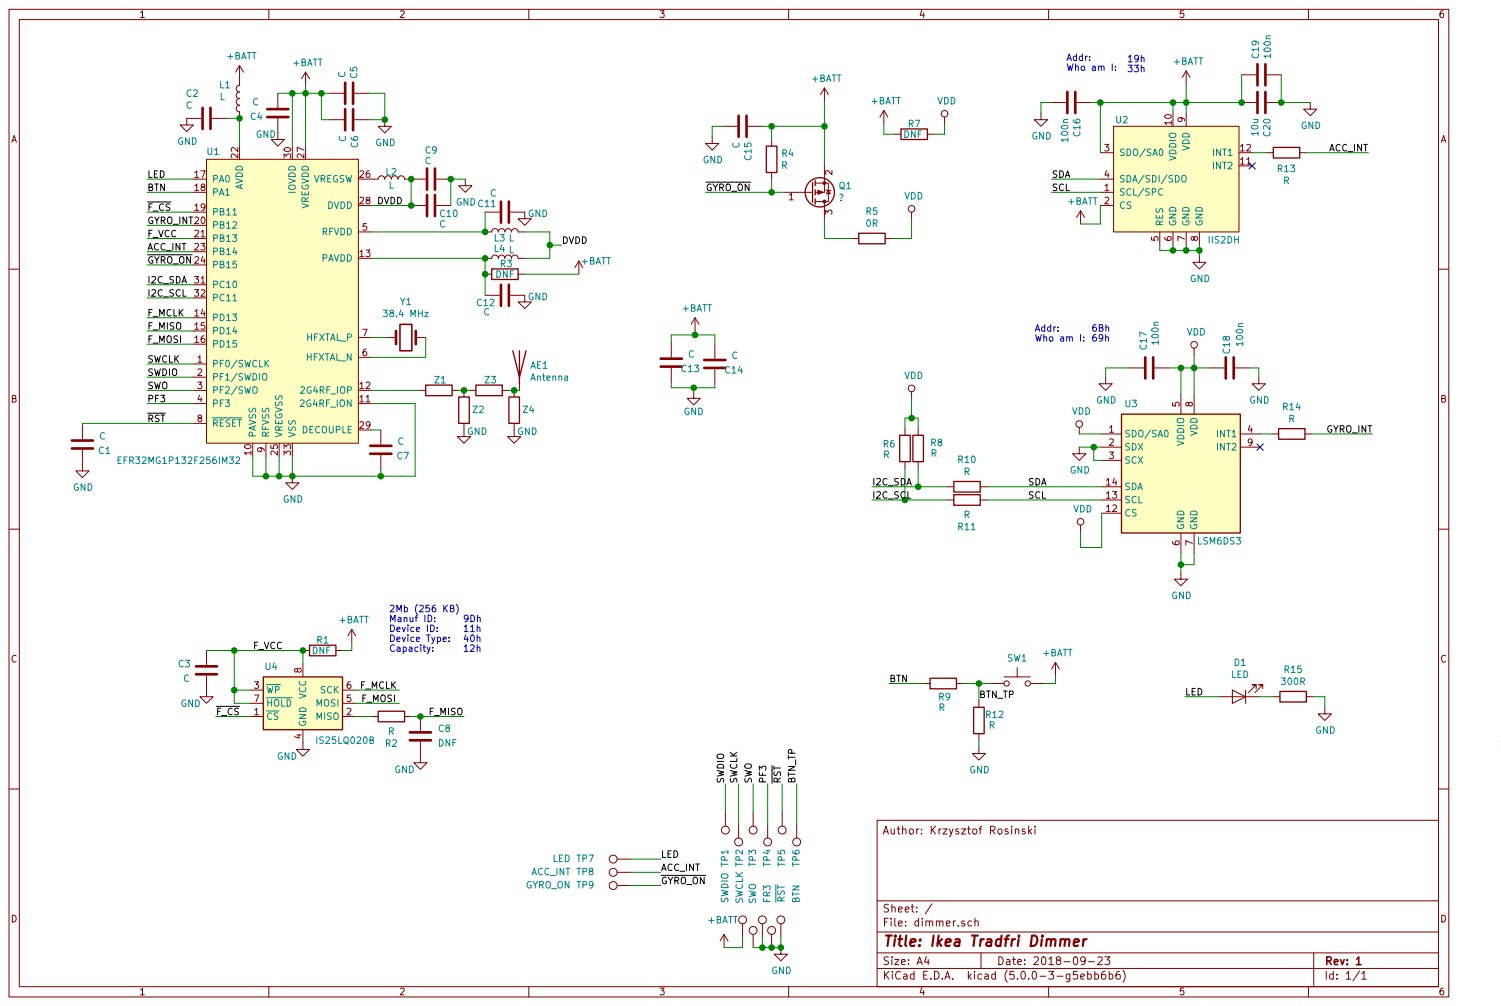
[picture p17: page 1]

2Mb (256 KB) Manuf ID: Device ID: Device Type:

4 MOSI 5 SCK 6 HOLD 7 VCC

+BATTSWDIO SWCLK SWO PF3 RST BTN_TP

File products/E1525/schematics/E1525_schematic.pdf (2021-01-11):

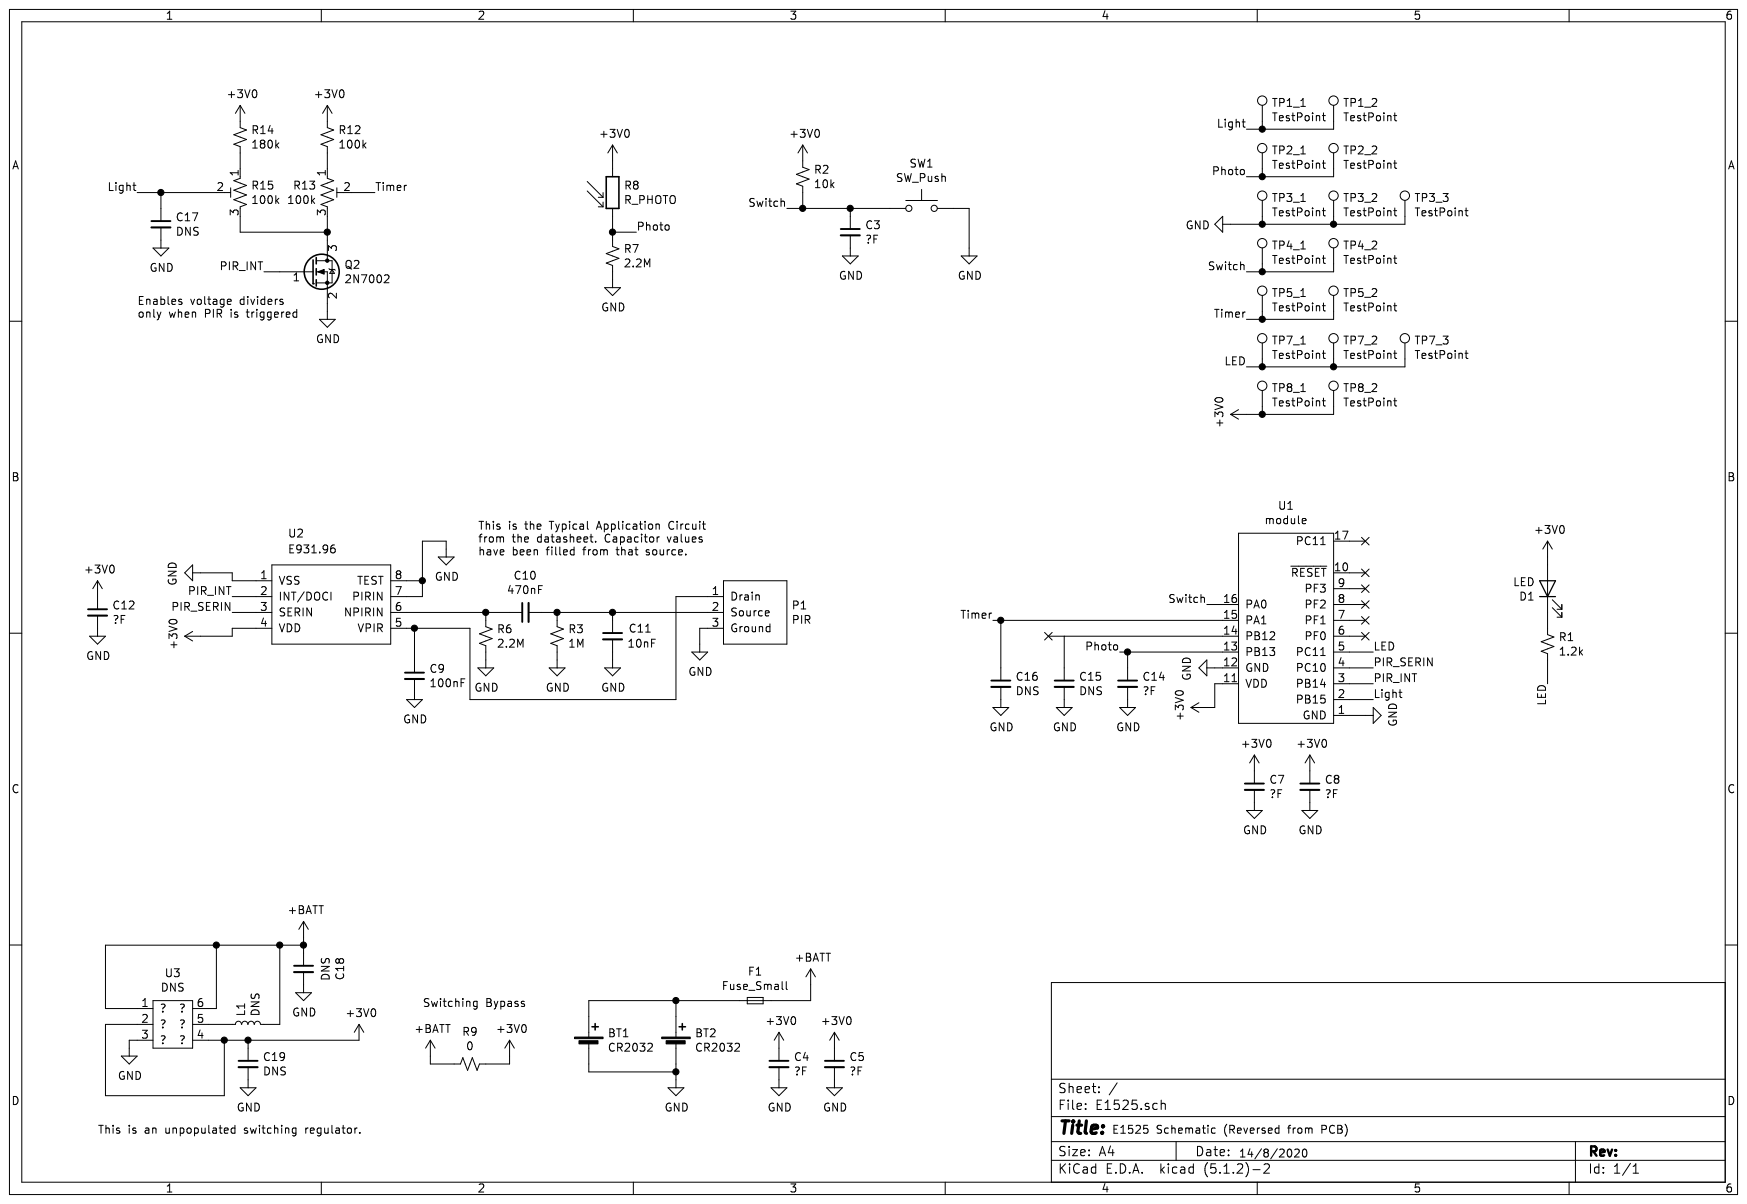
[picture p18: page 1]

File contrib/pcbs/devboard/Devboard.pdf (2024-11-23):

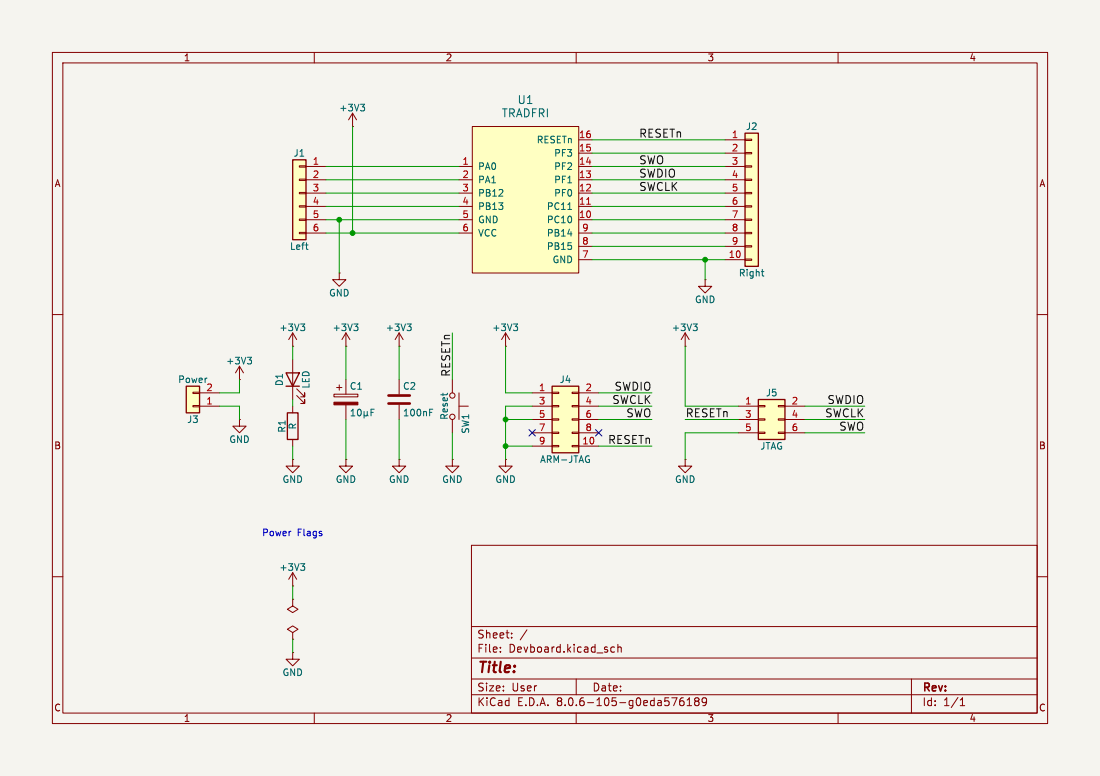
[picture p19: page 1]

2 | SWDIO | 4

5 | SWO 6 | RESETn

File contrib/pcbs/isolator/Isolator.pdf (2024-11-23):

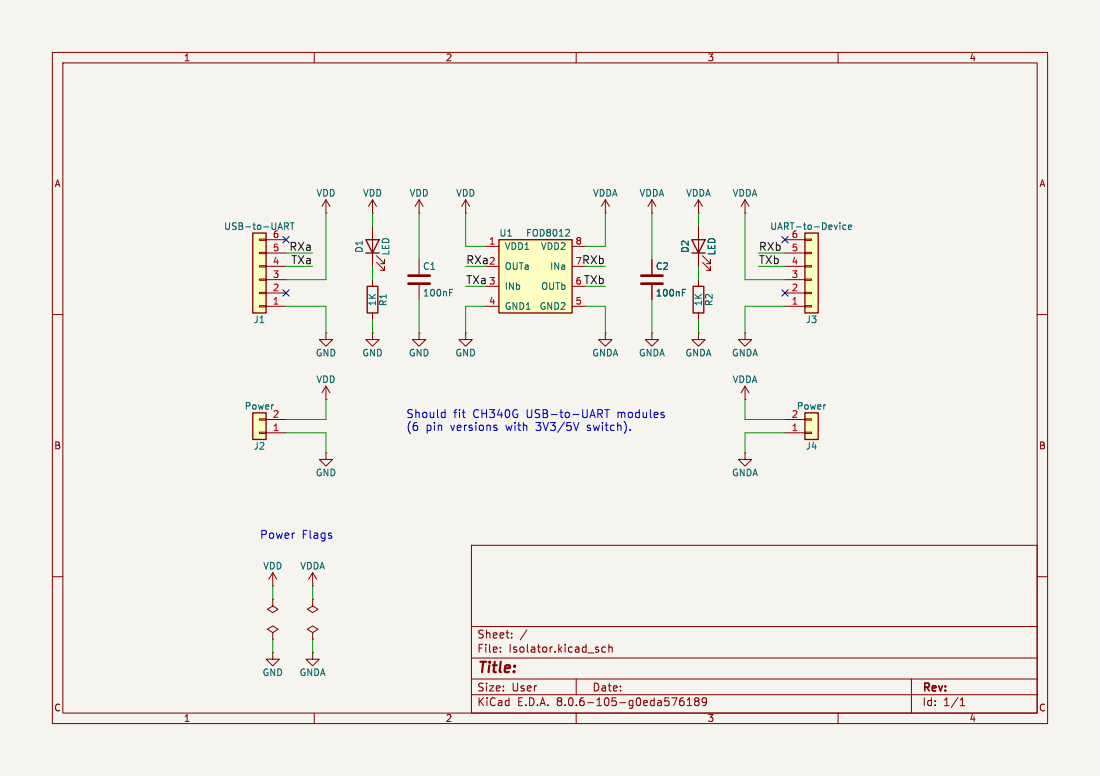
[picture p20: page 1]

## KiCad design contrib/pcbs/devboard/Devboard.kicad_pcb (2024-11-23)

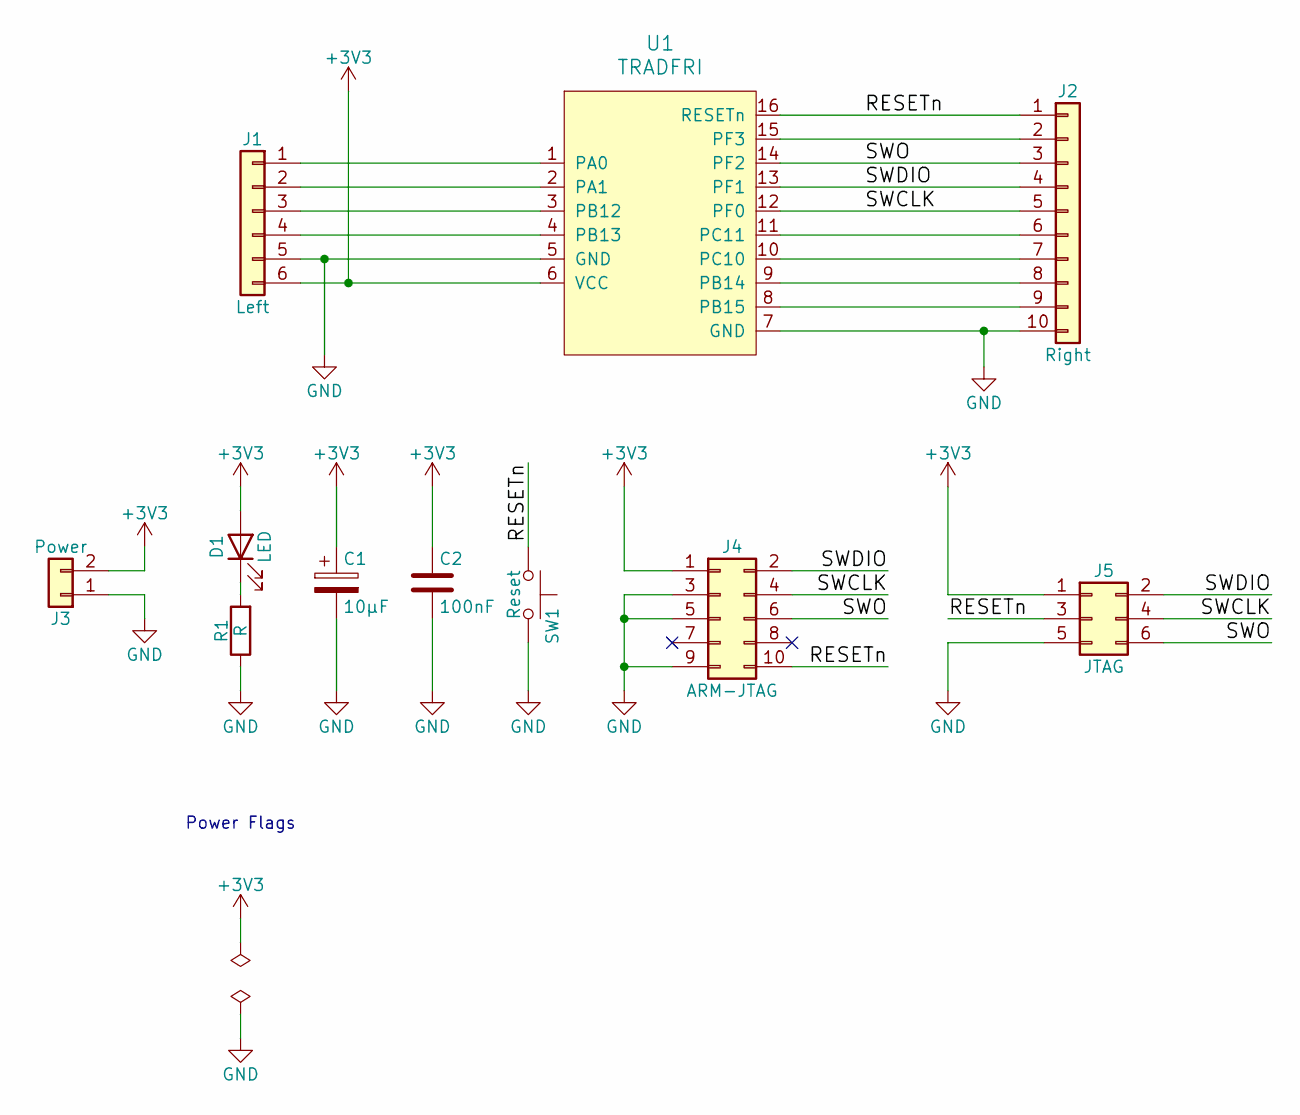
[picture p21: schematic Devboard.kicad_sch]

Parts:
C1: 10µF; CP_Elec_3x5.3
C2: 100nF; C_0805_2012Metric_Pad1.18x1.45mm_HandSolder
D1: LED; LED_0805_2012Metric_Pad1.15x1.40mm_HandSolder
J1: Left; PinHeader_1x06_P2.54mm_Vertical
J2: Right; PinHeader_1x10_P2.54mm_Vertical
J3: Power; PinHeader_1x02_P2.54mm_Vertical
J4: ARM-JTAG; PinHeader_2x05_P1.27mm_Vertical
J5: JTAG; PinHeader_2x03_P2.54mm_Vertical
R1: R; R_0805_2012Metric_Pad1.20x1.40mm_HandSolder
SW1: Reset; SW_PUSH_6mm
U1: TRADFRI; TRADFRI_PCB2.0

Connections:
+3V3: C1.1, C2.1, D1.2 (A), J1.6, J3.2, J4.1, J5.1, U1.6 (VCC)
/RESETn: J2.1, J4.10, J5.3, SW1.1, U1.16 (RESETn)
/SWCLK: J2.5, J4.4, J5.4, U1.12 (PF0)
/SWDIO: J2.4, J4.2, J5.2, U1.13 (PF1)
/SWO: J2.3, J4.6, J5.6, U1.14 (PF2)
GND: C1.2, C2.2, J1.5, J2.10, J3.1, J4.3, J4.5, J4.9, J5.5, R1.1, SW1.2, U1.5 (GND), U1.7 (GND)
unnamed: D1.1 (K), R1.2
unnamed: J1.1, U1.1 (PA0)
unnamed: J1.2, U1.2 (PA1)
unnamed: J1.3, U1.3 (PB12)
unnamed: J1.4, U1.4 (PB13)
unnamed: J2.2, U1.15 (PF3)
unnamed: J2.6, U1.11 (PC11)
unnamed: J2.7, U1.10 (PC10)
unnamed: J2.8, U1.9 (PB14)
unnamed: J2.9, U1.8 (PB15)

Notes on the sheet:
Power Flags

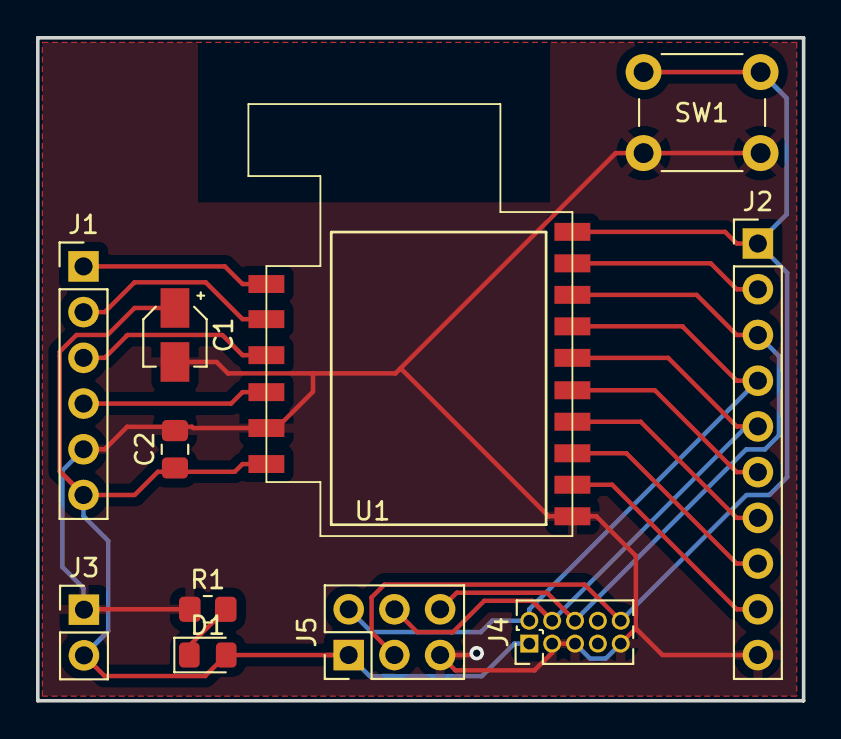
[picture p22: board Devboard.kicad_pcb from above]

Board: 2 copper layers, 42.5 x 36.8 mm, 11 parts (0 on the bottom side), 16 nets.

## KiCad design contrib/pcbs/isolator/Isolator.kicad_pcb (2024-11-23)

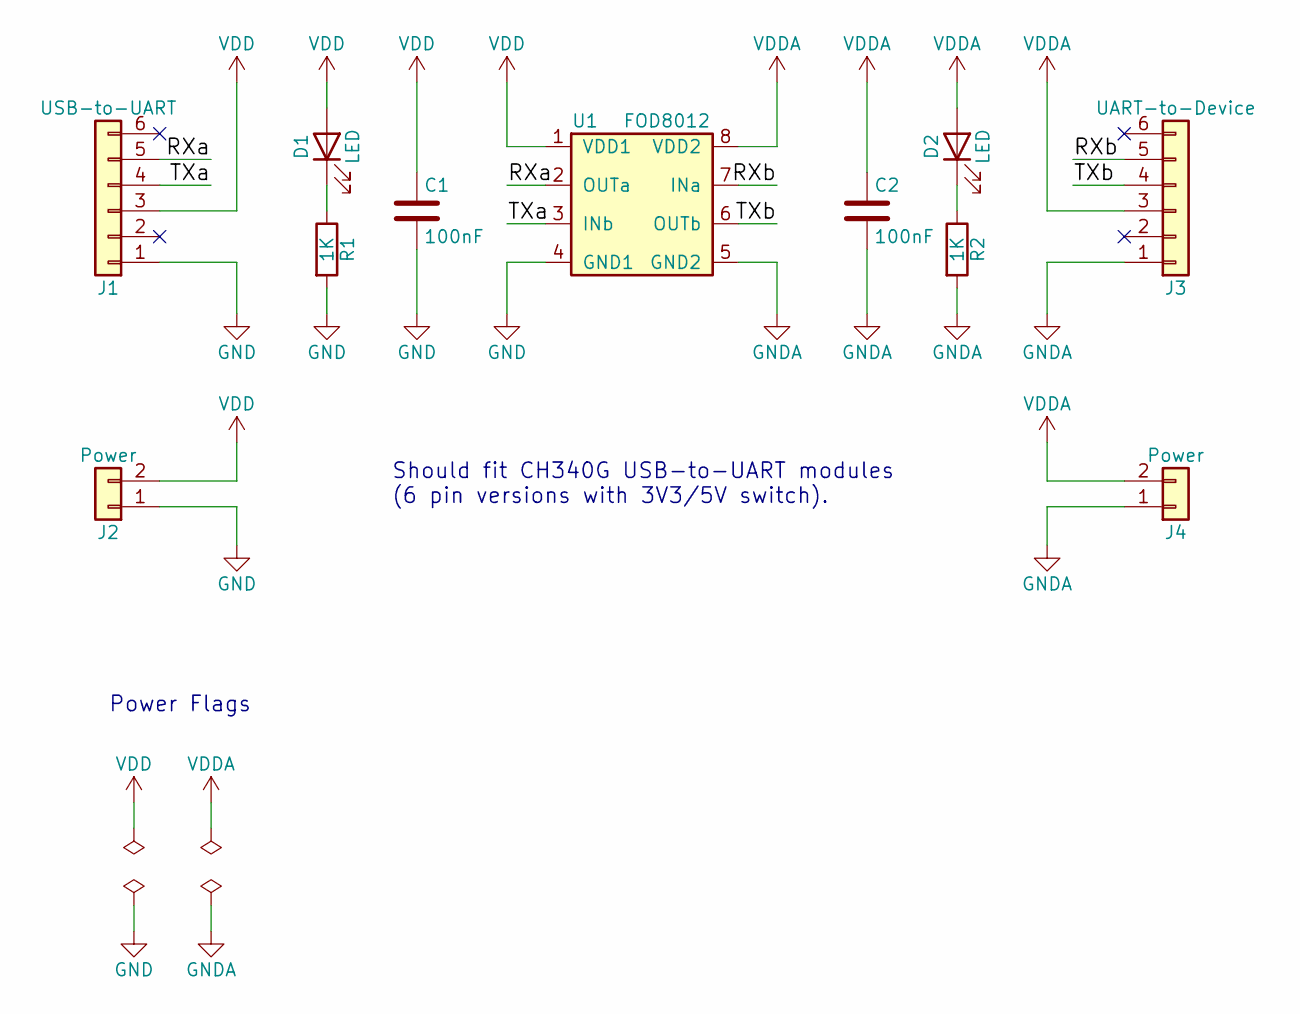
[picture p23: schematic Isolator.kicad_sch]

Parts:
C1, C2: 100nF; C_0805_2012Metric_Pad1.18x1.45mm_HandSolder
D1, D2: LED; LED_0805_2012Metric_Pad1.15x1.40mm_HandSolder
J1: USB-to-UART; PinHeader_1x06_P2.54mm_Vertical
J2, J4: Power; PinHeader_1x02_P2.54mm_Vertical
J3: UART-to-Device; PinHeader_1x06_P2.54mm_Vertical
R1, R2: 1K; R_0805_2012Metric_Pad1.20x1.40mm_HandSolder
U1: FOD8012; SOIC-8-N

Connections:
/RXa: J1.5, U1.2 (OUTa)
/RXb: J3.5, U1.7 (INa)
/TXa: J1.4, U1.3 (INb)
/TXb: J3.4, U1.6 (OUTb)
GND: C1.2, J1.1, J2.1, R1.2, U1.4 (GND1)
GNDA: C2.2, J3.1, J4.1, R2.2, U1.5 (GND2)
unnamed: D1.1 (K), R1.1
unnamed: D2.1 (K), R2.1
VDD: C1.1, D1.2 (A), J1.3, J2.2, U1.1 (VDD1)
VDDA: C2.1, D2.2 (A), J3.3, J4.2, U1.8 (VDD2)

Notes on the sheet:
Power Flags
Should fit CH340G USB-to-UART modules (6 pin versions with 3V3/5V switch).

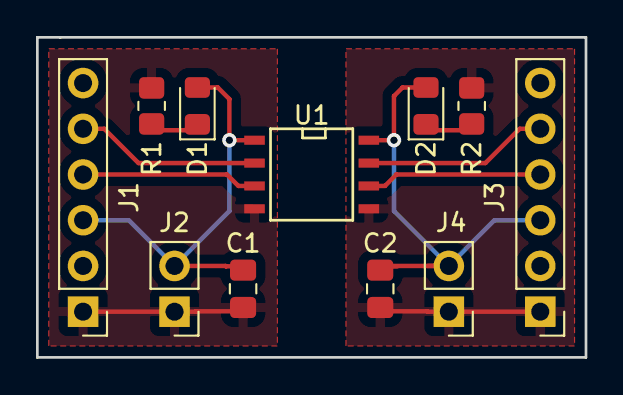
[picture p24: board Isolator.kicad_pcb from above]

Board: 2 copper layers, 30.5 x 17.8 mm, 11 parts (0 on the bottom side), 10 nets.

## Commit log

2017-11-16 Ignore Kicad files.
2017-11-16 Add schematic + pcb for an UART isolator (untested).
    [Isolator.kicad_pcb, Isolator.sch]
2017-11-16 Add schematic + pcb for a development board (untested).
    [Devboard.kicad_pcb, Devboard.sch]
2017-11-17 Add original firmware of GU-10 LED light.
2017-11-18 Updated devboard pcb, accidentally swapped GND and VCC line.
    [Devboard.kicad_pcb, Devboard.sch]
2017-11-19 Add CAD files of PCB.
    [tradfri.FCStd, tradfri.dxf, tradfri.stl]
2017-11-19 Updated PCBs
    [Devboard.kicad_pcb, Devboard.sch, Isolator.kicad_pcb]
2017-11-19 Add 3D PCB renders.
2017-11-19 Identified SPI flash.
2017-11-19 Dump strings and heatmap of original firmware.
2017-11-19 I'm more certain about the SPI flash chip used.
2017-12-27 Isolator devboard built and tested.
    [Isolator.sch]
2018-05-21 Fixed edge cuts. Upgrade tot Kicad 5.0-rc2.
    [Devboard.kicad_pcb, Devboard.sch]
2018-05-21 Update PDF schematic and PNG image.
2018-06-02 Add OTA firmwares
    Dresden-Electronik has a nice python script that allows one to download
    the Over The Air Update files from the ikea servers [0]. For archiving purposes
    it is usefull to mirror them here.
    Also attached a few versions of version_info.json pointing to these public files.
    [0] https://github.com/dresden-elektronik/deconz-rest-plugin/blob/master/ikea-ota-download.py
2018-06-04 Name appropiate device
    The pictured devices in the source under ICPSHC24 is actually a FLOALT L1529. This can be seen on the background where it says L1529. The transformer is part of the FLOALT in this case. This also is 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
2018-06-04 Add ICPSHC24-10EU-IL-1 (10W LED driver/dimmer)
    After getting a 10 Watt transformer I opened it for documentation purposes.
    Find the teardown and product information.
    The power control unit appears to be identical to the ICPSHC24-30EU-IL-1
    as can be seen in PR #7. Further investigation is needed and likely
    deblobbing/soldering to confirm some traces.
    U1 does not seem to be controlled by the rf-module, but is very likely to be a buck converter (24 V -> 3.3 V).
2018-06-20 Pinout / wiring of the motion sensor board
    Obtained by groping the PCB with a continuity tester, and carried over
    from personal notes.
2018-08-27 teardown: ICSPSLC24-10NA controller
    The ICSPSLC24-10NA controller sits at the end of the LED driver chain
    on the LED drivers such as the ICPSHC24-30EU-IL-1 and ICSPHC24-10EU-IL-1.
    It takes 24 Volts as its input and toggles its single output (On/Off/PWM).
2018-08-27 schematic: ICPSLC24-10NA PWM module
    With the teardown of the ICPSLC24-10NA module complete, a KiCAD
    schematic has been drawn to understand its exact function.
    A PCB design has been excluded at this moment.
    Note: The buck regulator is not part of the standard library, but
    is on its way upstream to the digi-key kicad repo and likely the
    default kicad repo as well.
    [ICPSLC24-10NA.kicad_pcb, ICPSLC24-10NA.sch]
2018-08-28 teardown: Add ICPSHC24-30EU-IL-1 (30W LED driver/dimmer)
    The ICPSHC24-30EU-IL-1 seems to be the big brother of
    the ICPSHC24-10EU-IL-1 with the only real difference being the power
    supply.
    This patch takes ludwo88's PR #7 photo's and creates a more appropiate
    merge request.
    Closes #7
2018-09-30 Add dimmer pinout + schematic
2020-01-11 Add teardown of the LED1837R5.
2020-01-11 Add picture of soldered development board.
2020-01-11 Add teardown of LED1537R6.
    Pictures and information by @rezolf, contributed via
    https://github.com/basilfx/TRADFRI-Hacking/pull/17.
2020-01-11 Add dumps of the LED1837R5 v2.1.022 firmware.
2020-01-11 Add information on SPI NOR Flash contents.
2021-01-11 Add LED1923R5
    Mentioned in https://github.com/basilfx/TRADFRI-Hacking/issues/39.
2021-01-11 Add photos of module PCB
2021-01-11 Added E1745 Motion Sensor
    Added the E1745 Motion Sensor, an updated (and kind of worse) version of the E1525. Seems to be pretty similar tho with some differences on the PCB markings. Further investigation and firmware dumpin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
2021-01-11 Add E1525 Details
    Added a schematic and additonal information on the E1525 sensor.
2021-01-11 Add pictures
    Added front and back photographs of the PCB
2021-01-11 Structure images and schematics.
2021-01-12 Document external antenna.
2023-09-24 Add E1812 shortcut button
2024-03-15 Add teardown of E2123 - Symfonisk Sound Remote Gen2
    Module used: https://www.silabs.com/wireless/zigbee/efr32mg21-series-2-modules/device.mgm210la22jnf
2024-06-01 Add IKEA PARASOLL door/window sensor
2024-08-20 Add hardware info about BADRING water leakage sensor (E2202)
2024-11-18 Add two scope screenshots
    These screenshots show how the PARASOLL reads the switch status about
    five times per second, for approximately 30 milliseconds.
2024-11-18 Move less-related stuff to contrib folder
    [Devboard.kicad_pcb, Devboard.sch, Isolator.kicad_pcb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]
2024-11-18 Move archived OTA files to contributed
    I currently have no better place to store them, because from the file
    names it is not clear to which product they belong.
    Might revisit this in the future.
2024-11-23 Rework contributed PCBs
    * Upgrade to KiCad 8
    * Improved PCBs
    * Added Makefile for automation of schema and board renders
    [Devboard.kicad_pcb, Devboard.kicad_sch, Devboard.sch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]
2024-11-25 Add IKEA ÅSKVÄDER on/off button
2024-11-25 Add IKEA ORMANÄS led strip
2024-11-25 Add IKEA TRETAKT smart switch
2024-11-28 Add IKEA INSPELNING smart switch
